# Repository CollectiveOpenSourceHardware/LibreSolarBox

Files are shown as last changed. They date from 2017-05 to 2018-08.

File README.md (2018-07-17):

# Libre Solar Box
This Open Hardware project is about the development of a solar box.
We want to provide a compact, mobile and modular electric power generator. An alternative to the diesel generator.
The power specifications are chosen to supply a mini house, a boat, a caravan, or any other off-grid devices like a music station on an open-air.

The aim is that everybody is possible to rebuild the solar box at home or at his/her favourite fablab.

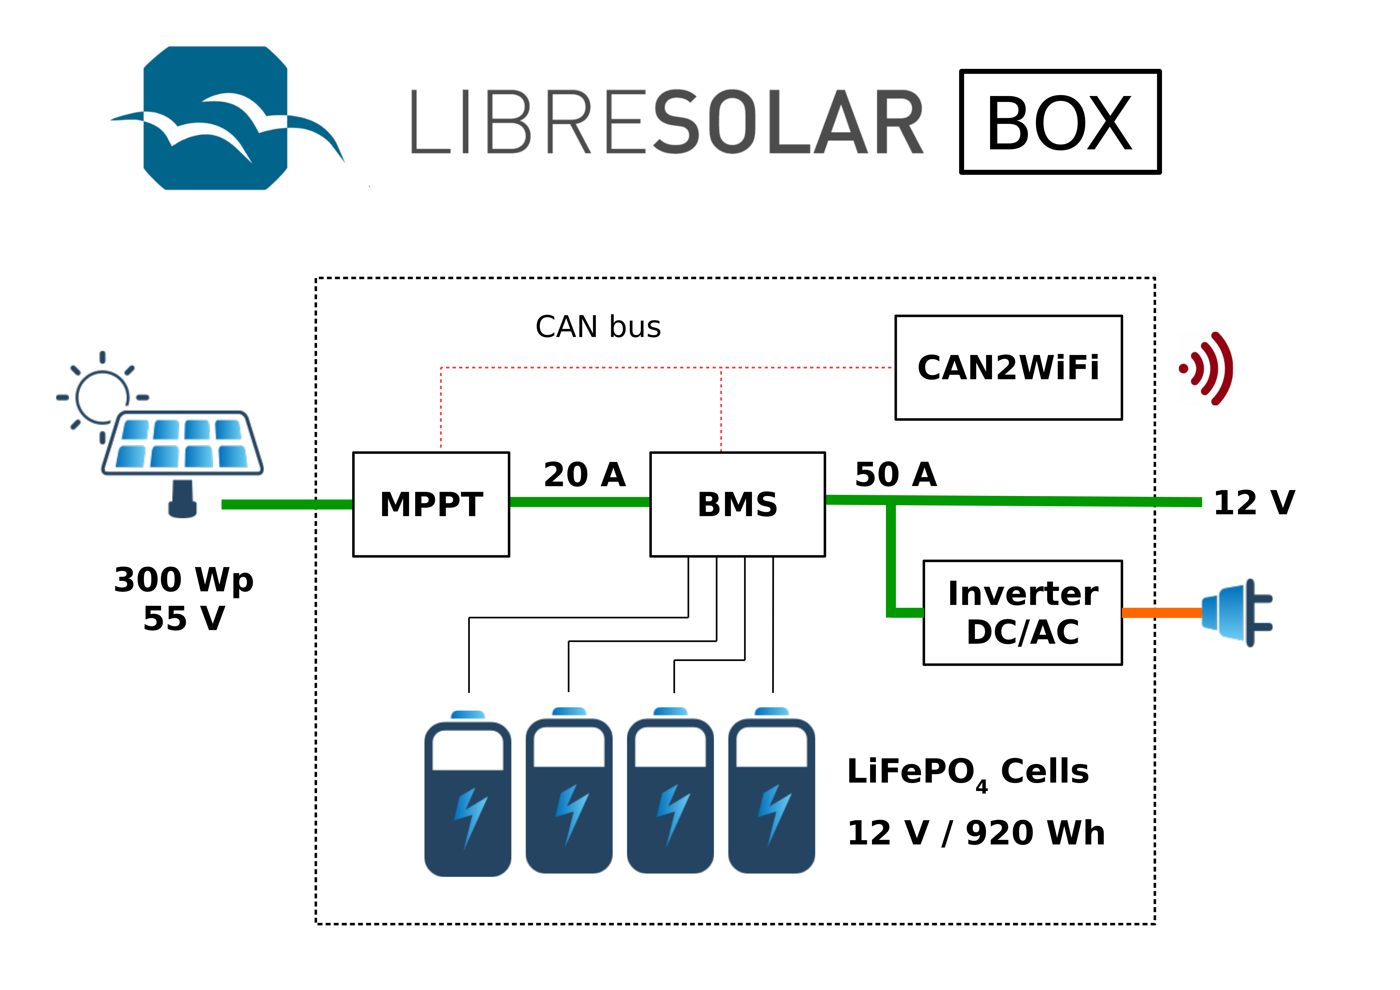
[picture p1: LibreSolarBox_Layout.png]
Layout


----------------------
## current system layout, V0.1
The current Libre Solar Box system contains following specs and modules:
### specs:
- V_input_max = 55V
- P_input_max = 300Wp
- C_batteries = 920 Wh
- V_dc_out = 12V
- P_dc_out = 300W, theoretically 600W -> not tested
- (V_ac_out = 230V, 50Hz) optional
- (P_ac_out = 250W) optional -> depend on inverter

### modules:
- **electric**: [Libre Solar](http://libre.solar/) (MPPT+BMS), Inverter (Victron), ESP/Rasbperry, Fuse
- **Batteries**: LiFePO4 (Calb), 72Ah, 3,2V, 230,5Wh - 4x -> 12,8V, 920Wh
- **Housing/Frame**: [UniProKit](https://wiki.opensourceecology.de/Upklib), with corner elements for blending; wood plates for mounting electric parts and batteries
- **Interface**: Solarinput (MC4), DC-output (car plug), AC-output (schuko, integrated in inverter), main switch

### visualization:
- [Open Energy Monitor](https://openenergymonitor.org/) via CAN to ESP (Server ext.)/Rasbperry (Server int.)
- browser based visualization -> access via LAN/WLAN

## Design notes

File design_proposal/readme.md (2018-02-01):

in this folder we want to propose some designs how you can enclosure the box components to a moveable scalable box

## First designs
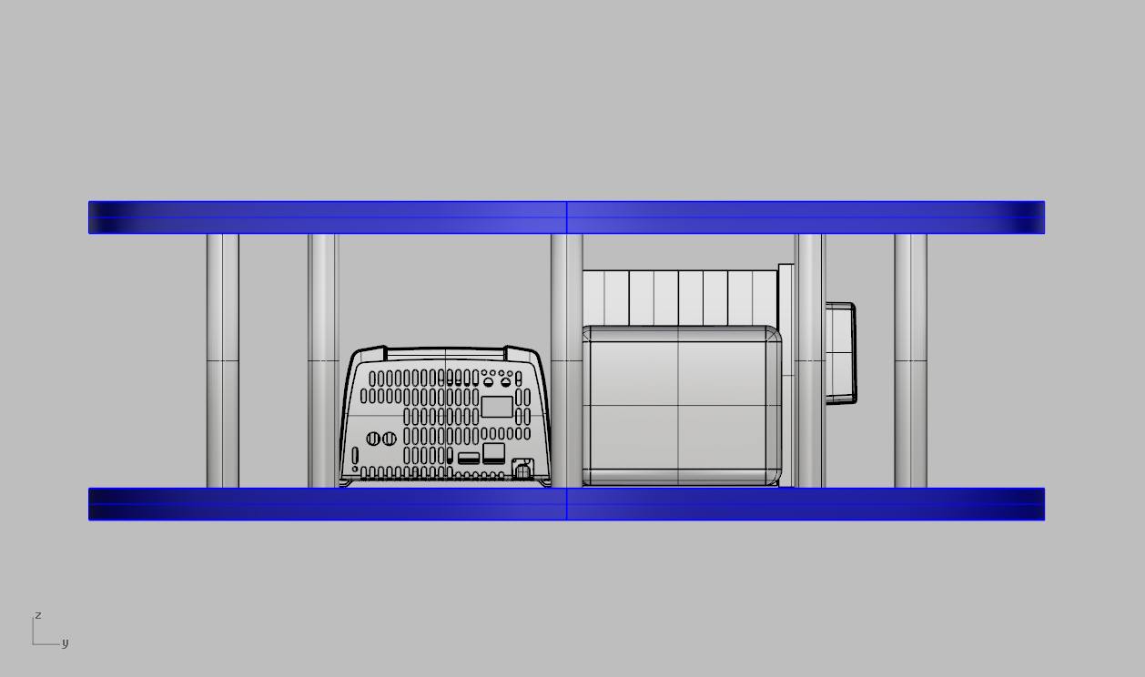
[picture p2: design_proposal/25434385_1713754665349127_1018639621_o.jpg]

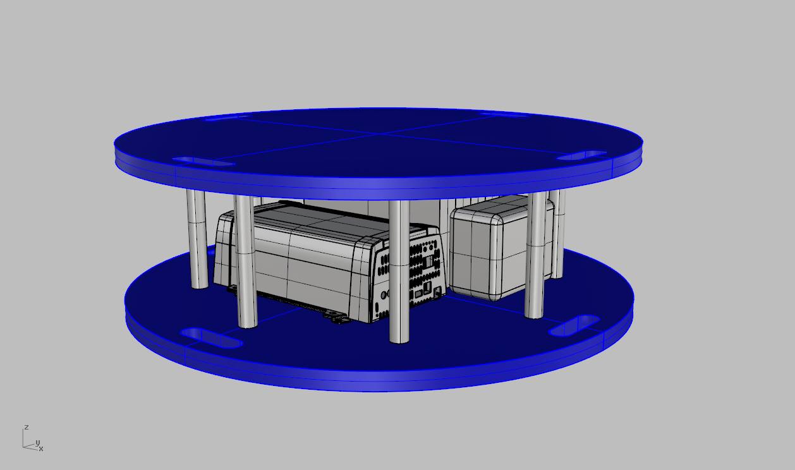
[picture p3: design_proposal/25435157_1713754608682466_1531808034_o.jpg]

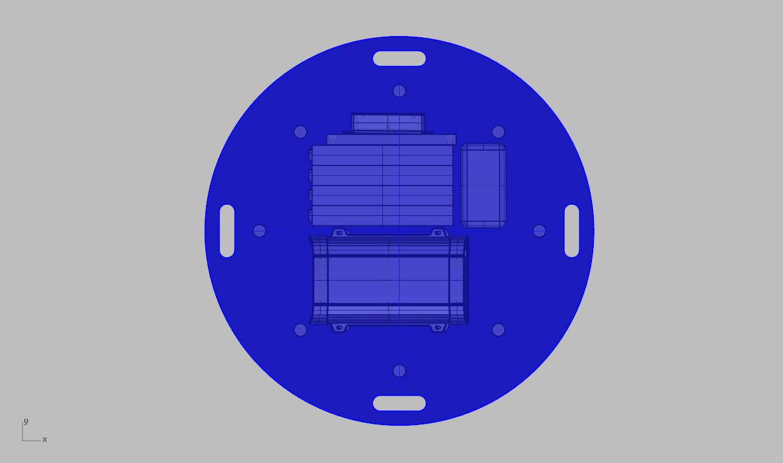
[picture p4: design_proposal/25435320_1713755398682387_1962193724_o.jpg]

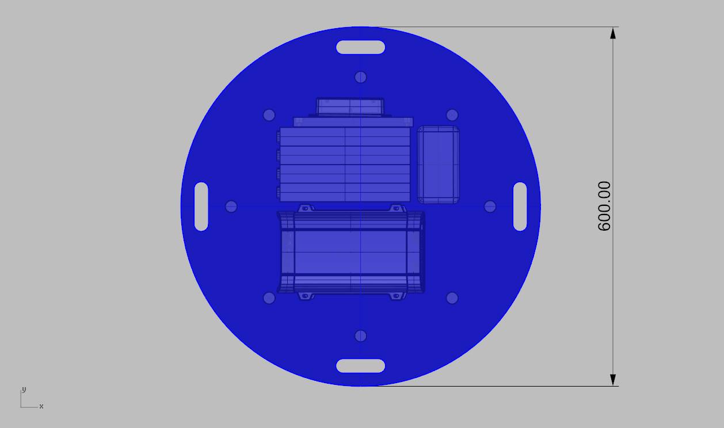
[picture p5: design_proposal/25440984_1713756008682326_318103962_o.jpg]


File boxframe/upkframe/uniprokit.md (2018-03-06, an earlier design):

## The UniProKit 

The UniProKit (Universal Prototyping Kit) project was originated by the wish to have a kind of open universal construction kit available, based on the principles of OpenSource/OpenHardware.

It should resemble the well known '''metal construction sets''' like Meccano/Erector, with basic elements like bars, angles and plates with rows of drilled holes, wheels, flanges, transmission-rods etc., up to more specific elements like stepper motors and linear drives, less toy-like, but more stable and slightly bigger dimensioned.



### Applications

Such a thing would be desirable for all kind of projects, for fast and easy testing of approaches and ideas - just rapid prototyping, or for building smaller machines like a 3D-printer or pcb-router. It could also be used for structural supports and mountings in experiments, or jigs for producing other parts. One can also use it for building assembly groups and modular components in other projects, e.g. a lineardrive-module within a tracking-system.



The application range is wide and similar like those commercial and aluminium-extrusion-profiles based T-slot-systems often used by engineers, but we dont want to be limited only on such quite expensive system-solutions. It is an important aspect of the UniPro-Kit Sets, that they are consisting mainly of these parts, which are easy and everywhere available, like in the next local hardware store. Or one can make use of materials like aluminum-profiles, which can become DIY-processed with hand-tools and simple jigs, e.g. drilling rows of holes and cutting at different lengths.

It is an important and typical part of the OSE-concept, to become independent of industrial producers, not absolutely and by 100%, but as much as possible.

### Compatibility and Systematics

Within the ongoing development of this project eventually occurred - as a kind of by-product - the idea, to make the UniPro-Kit open and extendable towards all directions and to support any possible kind of compatibility with other Open Hardware Construction sets like Gridbeam, OpenStructures and Openbuilds, etc., and to integrate and combine all these and others together into a kind of open standard.

Now we try to define conditions and criteria of a classification-systematics, in which all kind of parts from different other construction sets can become integrated and registered, getting a unique part-no., and act as a common base for a kind of catalog-system or parts-database.

Systematics

The aim and our hope is, that such parts would be preferred and more often used in many maker-projects, so that it may later results in a kind of independent de-facto-standard of OpenHardware-parts.

### Advantages 

This would offer the following advantages:

* each part that was integrated into this system contains in its database-entry at least a reference on a source of supply and a technical drawing. In some cases there may be also a detailed description how to produce this part on your own with appropriate tools and jigs ("DIY-able").

* in case of some parts which are not so easy to produce some groups or Open Hardware projects may specialize themselves on producing and offering them the Open Hardware Community to buy. This could lead into a small market with independent suppliers ( like "OpenSourceEconomy").

* the parts and their producing-process itself can be optimized by the community and better adopted at the specific demands of the individual Openhardware projects.

* one can use OpenSource-CAD-libraries of the parts, which allow a pure virtual construction, development and optimization of Open Hardware projects by a big developer-community, longtime before its necessary, to spend real money for materials or having access to well equipped workshops.

* the systematics and the database would allow a direct search and access of special parts. That's different compared to sites like thingiverse, on which also exists a lot of useful things, but they are only small organized and less catalog-like, so it needs a time-consuming search to find there the appropriate thing.

### Status 

The recent state of the project is, that we have already fully defined the so called **Basic-Set**, which is appropriate for all kind of structural framing and mounting stuff and provide it for download as part-library **UPKlib V.2**). It is made consequently with the OpenSource CAD-programm **FreeCAD**, which means it can be exported from there into many important CAD-fileformats like .igs, .stp, .stl etc.  



Other sets are under development, like the **LinearDrive Set** for linear motion of cnc-maschine-axis and the **Frame Set**, which contains useful parts for housing, like corner-elements and cover-plates.  

More sets are in preparation, each one related to a certain area or theme, like electronic-pcbs and stepper-motors. Since this is an open system, all kind of useful sets can be added by time or on demand.  Meanwhile we can use them as working-examples, for discussing and developing different contents and practical aspects of the systematics.

It would be nice and certainly useful for everyone, if such a kind of systematics could be well established as an independent standard of parts and parts lists in Open Hardware projects.  Whether this will really happen or not depends on different facts and influences, like e.g. the acceptance of the community.

### Links 
* Project-Homepage: [UniProKit](https://wiki.opensourceecology.de/Universal_Prototyping_Kit)
* The CAD-Library: [UPKlib V.2](https://wiki.opensourceecology.de/Upklib)
* Structural Parts: [Basic Set](https://wiki.opensourceecology.de/Basis-Set_Strukturelemente)
* Housing: [Frame Set](https://wiki.opensourceecology.de/Erg%C3%A4nzungs-Set_Frameset)
* Linear Motion : [LinearDrive Set](https://wiki.opensourceecology.de/Erg%C3%A4nzungs-Set_Lineartrieb)

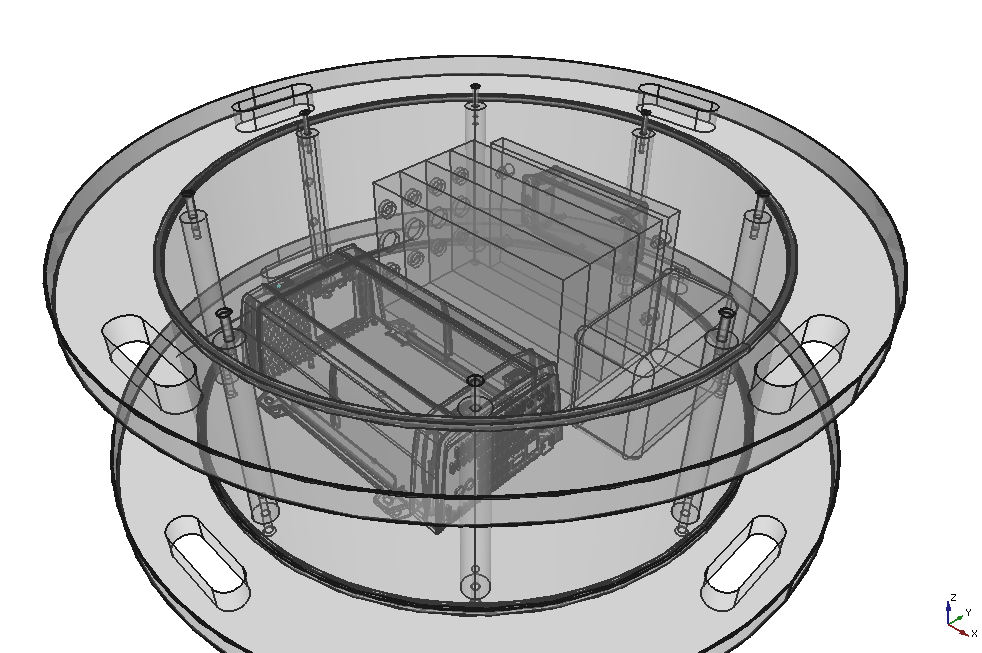
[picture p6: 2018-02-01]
design_proposal/Solarbox_Trommel_transparent.png

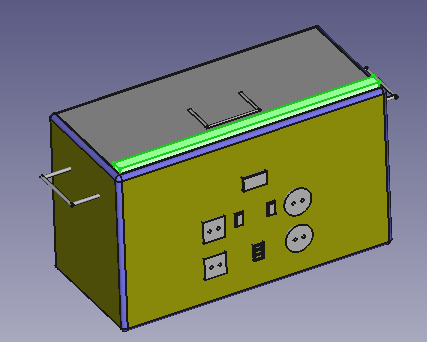
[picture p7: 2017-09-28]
Solar Box_FreeCAD Design/Solar Box v_3/solar_box_v_03_photo1.PNG

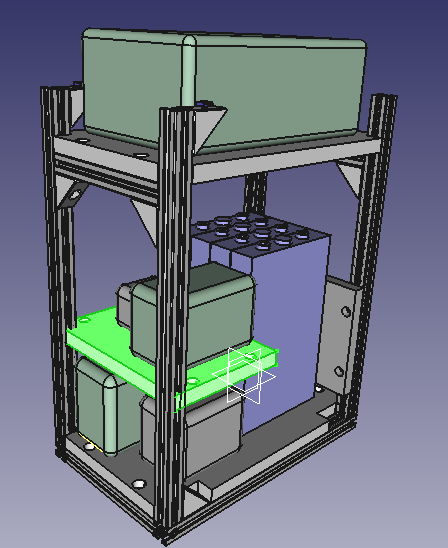
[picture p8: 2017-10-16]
Solar Box_FreeCAD Design/Solar Box v_4_ boxframe/Solarbox_v_04_boxframe_photo_2.PNG

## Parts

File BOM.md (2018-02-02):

## Bill of materials V0.2:

### Box Frame:
- UPK frame:
  - aluminium slot: size defined in 3D model
  - triangle connectors (for stabilization, @case06 whats the right word for it? :))
  - screws, ..., @case06  can you extend the list w/ all needed parts for the Uni Pro Kit w/o corner elements
- wood plates for cover -> thickness like alu profile
- wood plates for internal mounting of parts -> bottom, PCB mounting, analog V0.1
- corner elements -> 3D modelled options (@jocogergely if you can you can make few suggestions, no prio)

### Electronics:
- MPPT, BMS, Gateyway/Server
- buck converter

### Interface:
- DC output plugs (12V car plug, 2x)
- Solar input plugs: Weidmüller PV Stick (assembly w/o crimping and compatible to MC4, clips should be removed to unplug without tools)
- USB plugs
- ON/OFF switch, pushbutton, integrated LED
- RJ45 jacks (2x)
- e-paper display+conncetion wire

### Internal Connections:
- Power wire (6mm^2, red+blue, each 1m)
- Balancing wire (2mm^2, 2m)
- Communication wire (ethernet cable, 0,5m)
- Ferrules, Cable lugs

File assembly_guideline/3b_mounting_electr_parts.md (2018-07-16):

# Assembly Workshop at the Fablab St.Pauli, 08. July 2018

### Preparation Steps
- Software tools
  - FreeCAD, 
- Prepare tools and place
-> foto of each part
  - table
  - crimping tool
  - screwdriver
  - side cutter
  - allen wrench
- Prepare material and components
  - Frame and Housing (in this case UniProKit)
    - screws, nuts
    - T-slot alu profile
    - 3D printed corner elements / connectors
    - bottom plate
    - housing plates
  - Battery pack
    - 3D printed battery case (bottom and cap -> download link to file)
    - battery cells
    - cell connectors
  - electrical components
    - Libre Solar components -> MPPT, *BMS*, (optional: CAN2Wifi)
    - (optional: RaspberryPi0)
    - wires - power wires (6 sq mm), balancing wires (2 sq mm)
    - ferrules, cable lugs
    - (optional: communication wire - ethernet cable)
   - plugs
     - *dc-output plugs (car plug, 2x)*
     - solar input plugs (Weidmüller PV Stick allows assembly w/o crimping and is compatible to MC4. Clips should be removed that the plug can be unmounted without tools)
     - *usb plugs*
     - *ON/OFF switch, pushbutton, integrated LED*
     - (optional: RJ45 jacks (2x))
     - (optional: epaper display+conncetion wire)

Remarks: Parts in *italic font* still need to be ordered.

### Assembly Steps
1. Frame assembly
- 1.1 nuts into t-slot profile (

//comment from Oliver: fotos, which shows for each side the placement (and numbers) of the nuts (sitting in the slots). This is the key-information needed when assembling a box the first time, in order to avoid repeatedly re-opening the frame for adding some forgotten nuts

- 1.2 place profile in rectangle, place corner elements between profiles, screw together
- 1.3 repeat 
- -> result: 2 connected rectangle frame
- 1.4 connect the 2 rectangle frames with profile
- -> result: boxframe
2. screw bottom plate on bottom side of boxframe
- -> result: boxframe with bottom plate
3. cut and crimping wires
- 3.1 ...
4. battery pack assembly -> !!!!!safety note!!!!!
- 4.1 put battery cells in battery case (bottom part)
- 4.2 connect battery cells together
- 4.3 connect balancing wires with cells
- 4.4 connect power wires with battery cells
- 4.5 screw battery pack with bottom plate
5. mouting of electric components
...

### Disassembly Steps
1. remove blending parts (sides, backs)
-> pic box, mark sides, mark screws
2. remove fuse! -> no voltage/ current in system, note for electric safety rules 
-> pic fuse
3. remove interface (plugs, swith), by cutting, by 
-> pic interface, mark points to remove
4. remove cables from electric components
-> pic components, pic interface/jack
5. demount electric parts
-> pic screws
6. 

## Disassembly ##
### Disconnect BMS:
* Remove fuse.
* Remove BAT+ cable. 
* Mask metal end of the cable .
* Remove BAT- cable.
* Mask metal end of the cable.
* Remove PWR+ cables from BMS.
* Remove PWR- cables from BMS.
* Remove thin cables from BMS
* Remove internet cables from BMS.
* Remove monitor cables.
* Move ends of the cable down. Keep them away from batteries.
* Remove thin cables.

### Remove upper part of the case
* Remove screws from the upper blending.
* Remove screws from handles.
* Remove the upper blending with the handles.

### Remove interface blending
Interface are the sockets on the blending.

* Remove thick cables from blending if they are not soldered.
* Remove screws from the blending. Put them into a cup.
* Desolder on/off-swich.
* Remove CAN Socket.
* Remove USB power socket.
* Remove two DC Out 1V sockets.
* Do not remove PV INPUT and OUTPUT from interface. In this version it is not mechanically possible yet. We need to disconnect them from MPPT first.
* Remove PV Input and OUTPUT cables from MPPT.
* Remove all other cables from MPPT.
* Remove the interface bleding.
* Remove PV Input and OUTPUT sockets with cables. Now it is possible to do.
* Put away the interface blending.

### Remove MPPT
* Remove screws which hold the MPPT.
* Put away MPPT.

### Remove BMS
* Remove screws which hold BMS at the battery case.
* Put away BMS.

### Remove remaining side blendings
* Remove remaining side blending and put them away.

Now you can easier access the batteries.

### Remove batteries
* Determine the in wich order you need to remove the batteries. We work from **main -** -- this is the first battery -- to **main +** -- this is the last battery.
* Carefully remove a screw, an electric connector, and a washer from one side of a battery block.
* Carefully remove a screw, an electric connector, and a washer from the other side of the battery.
* Put away the battery.
* Repeat it for all the remaining batteries.

### Dissassemble frame
* Lay the frame on a side. This is the side with the largest area.
* Remove four upper screws.
Before remove the frame, pay attention to the nuts in the frame. They can fall down after the next step.
* Put away the frame.
* Remove four screws which connects the remaining frame with the small aluminum profiles.

We have now two frames and for short aluminiums profiles.

* Remove screws throw the plastic corners of the both frames.
* Remove the plastic corners.

## Assembly
### Assembly frame box
Note: square nuts are not symmetric. When inserting them into T-Slot, keep the upper part outside. See picture [...] to determine the upper side of the nuts.

Create large squre frames first.

* Put larger profiles on the table and put plastic corners in the corners. Check orientation of the profiles. The holes on the side of the upper and the lower profile must be up.
* Insert all necessary square nuts in the T-slots.

 Hint: Use a bolt to push a square nut into a slot.

* Control the placement of corners, screws and squre nuts.
Start with the bottom part.
* Connect a corner to the bottom.
* Connect a side part to the bottom.
* Connect another corner to the bottom.
* Connect another side to the bottom.
* Connect remaining corners and the upper part.
* Connect small T-profiles to a big square frame. The holes on the side of the large frame must be later outside of the box.
* Insert nuts into short profiles. Two nuts into every short profiles on the top of the future box. Four nuts into every short profile on the bottom of the future box.

### Add bottom
* Add the bottom blending.

### Add batteries
* Mark the batteries with numbers *1*, *2*, *3*, and *4*.
* Put batteries into the battery case.
* Isolate main **+** and main **-** of the batteries. (Is it important to have main "+" or "-" on particular side of the battery block?")
Now carrefully connect batteries one by one, from *4* to *1*.
* Put connector between *4* and *3*.
* Put a washer on the connector on the side *4*.
* Put thin cable with tag *4* on the washer
* Put another washer on the connector of the thin cable. (Too many washers, check it again).
* Put a bolt throw connector, washers and thin cable and  tighten it. (bots or screws?).
* Put a washer on connector on side *3*.
* Put a bolt throw the washer and the connector and tighten it.
* Connect in the simmilar way batteries *3* with *2* and *2* with *1*.
* Do **not** remove isolation from main **+** and main **-** yet.

### Assembly interface bleding
The interface blending is the blending with sockets.
* Put sockets with cables into the blending
* Mount the interface bleding to the frame

### Connect BMS
* Solder cablers to the on/off-switch.
* Mount blue thick cables and USB+ to *PWR-* of BMS.
* Mount red thick cables and USB- to *PWR+* of BMS.
* Connect two blue cables (- or +?) to two DC out sockets.
* Connect two red cables to two DC out sockets.
* Connect two thin cables from on/off-switch to BMS.

### Connect to MPPT
* Connect all cable ends without blade connectors to MPPT.
* Check that these cable are well mounted.

### Connect battery block
(In this part BAT- and BAT+ seems to be confused.I need resolve it.)
* Remove isolation from **main -**.
* Connect two cables to **main -**.
* Connect thick blue cable to *BAT-* on BMS.
* Connect two cables to **main -**
* Connect balancing to *BAT-* on BMS. (Is this correct?)
(Must the on/off switch must be off before add the fuse? How one can see it?)
* Add fuse.
* Check the voltage (where?): It must be around 12.8 V.
* Switch off the on/off switch.
* Check the voltages. It must be falling until 0. The voltage does not drop imidiatelly to 0, because there is remaining electric charge in the capacitors.
* Swich on.
* Check Voltage between *POW+* and *POW-*. It must be about 12.8V.
* Remove the fuse. (I missted this step in my notes. Is it correct here?).

### Connect Raspberry
* Connect  an internet cable to Raspberry
* Connect the internet cable to BMS.
* Connect an internet cable to CAN socket on the blending.
* Connect the other end of the cable to BMS.
* Mount the Raspbery with two-side tape to the box.

### Add back blending
(Better do it before interface blending because the inteface blending is not flat.)
* Put SolarBox on the interface.
* Position square nuts. They must have the same position as the holes of the blending.
* Put blending on the frame.
* Insert bolts through the blending into the square nuts. Tighten the bolts.

### Mount side blending
* Put the SolarBox on the side.
* Position the squre nuts.
* Put the blending on the frame.
* Insert bolts through the blending into the square  nuts. Tighten the bolts.

### Mount to blending with handles.
* Put the SolarBox on the bottom.
* Position squre nuts for the top blending.
* Put top blending.
* Put handles on the top blending.
* Insert **longer** bolts through the handles, the blending and squre nuts. Use normal bolts for other parts of the blending.
* Tighten the blending.

### Mount last side blending
* Check once more if all the connection are good.
* Insert the fuse.
* Put the SolarBox on the side.
* Position the square nuts.
* Add the blending.
* Tighten the bolts.

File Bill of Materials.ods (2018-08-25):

# | Material | quantity | Material/design type/ comments | dimention | Manufacturer | Supplier/Seller | Price
1 | Uni Pro kit (UPK) | 1 set |  |  |  | Oliver
2 | Wooden side plates | 4 plates | wooden ply |  |  | Oliver
3 | Acrelic side plate cover | 1 plate | tranperant |  |  | Oliver
4 | Wooden bottom plates | 1 plate | wooden ply |  |  | Oliver
5 | Wooden Extra plates for battery Holder |  | wooden ply |  |  | Oliver
6 | Battery Holder 3D printed | 1
7 | Handel 3D printed | 2 | 3d printed |  |  | Oliver
8 | Corner 3D printed | 4 | to assumble UPK part
9 | Fuse | 1
10 | Display | 1
11 | MPPT | 1
12 | BMS | 1
13 | Inlet + Outlet Solarpanel connector | 1 set
14 | DC 12V outlet plug | 2
15 | USB 5V outlet plug | 1
16 | CAN output plug | 1
17 | On/Off button | 1
18 | Battery Cell | 4
19 | Battery Cell connector plates | 3
20 | Battery Cell connector screw | 8
21 | RasPi - CAN to wifi connection | 1
22
23
24
25 | Screw - Handel of UPK | 4
26 | Small Screw - outer panel of UPK
27 | Nut for outer panel of UPK
28 | Big cornor Screw - to addemble UPK frame in cornor | 8
29
30 | Screw - MPPT/BMS connection | 10 | 5x2
31 | Screw - MPPT/BMS installation | 8 | 4x2
32 | Disply | 1
33
34
35
36
37 | Wire - thick - red & blue | 10 | to all main connection from battery to MPPT & BMS | 0.25m (5 Red color & 5 Blue colour)
38 | Wire - thin - blue | 6 | to connect BMS to battery to check Battery status | 0.4mx6 (blue colour)
39 | Wire - very thin - black | 3 | to connect power button to MPPT | 0.25mx2, 0.4mx1
40 | LAN cables | 3 |  | 0.25 m
41 | wire connectors

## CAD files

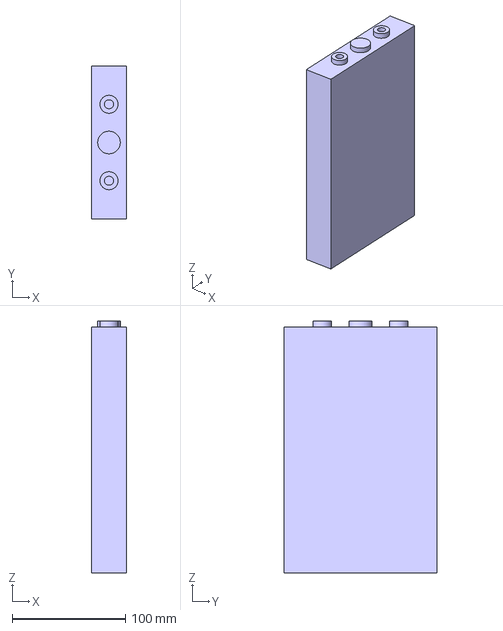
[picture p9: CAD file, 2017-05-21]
batterycase/celltypes/CALB_CAM72/cam72_calb3.fcstd
31.0 x 135.1 x 222.5 mm

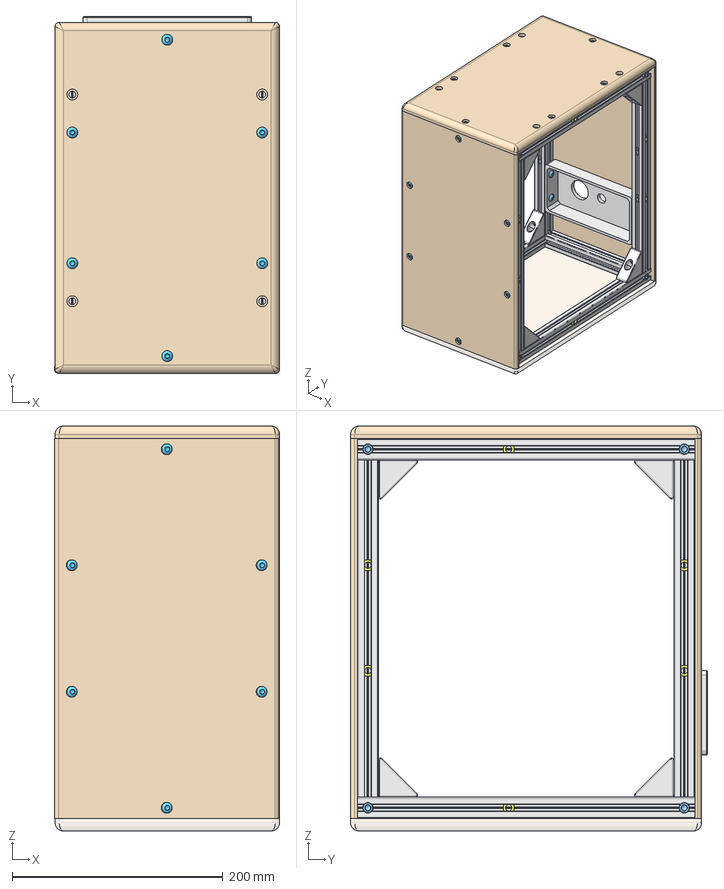
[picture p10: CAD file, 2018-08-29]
boxframe/buildinstructional/cover/cover8.fcstd
213.5 x 338.5 x 384.0 mm
tslot32con
tslot16
tslot16_001
tslot32con_001
M6x25-Screw
M6x25-Screw004
M6x25-Screw005
M6x25-Screw006
tslot32con001
tslot041
tslot16_002
tslot32con_002
M6x25-Screw012
M6x25-Screw015
M6x25-Screw017
M6x25-Screw016
m6nutplate020uf
m6nutplate021lf
m6nutplate022lf
m6nutplate023lf
m6nutplate024lf
m6nutplate025lf
m6nutplate026lf
m6nutplate027lf
m6nutplate028uf
m6nutplate029uf
m6nutplate030lf
m6nutplate031lf
m6nutplate032uf
m6nutplate033lf
upright4
m6nutplate025uf001
m6nutplate022uf001
m6nutplate031lf001
M6x12-Screw022
upright005
m6nutplate031lf002
M6x12-Screw025
upright006
m6nutplate031lf003
M6x12-Screw028
upright007
m6nutplate031lf004
M6x12-Screw031
m6nutplatesidecover
m6nutplatesidecover001
m6nutplatesidecover002
m6nutplatesidecover003
m6nutplatesidecover004
m6nutplatesidecover005
m6nutplatesidecover006
m6nutplatesidecover007
m6nutplatefrontcover
m6nutplatefrontcover001
m6nutplatefrontcover002
m6nutplatefrontcover003
m6nutplatefrontcover004
m6nutplatefrontcover005
m6nutplatefrontcover006
m6nutplatefrontcover007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

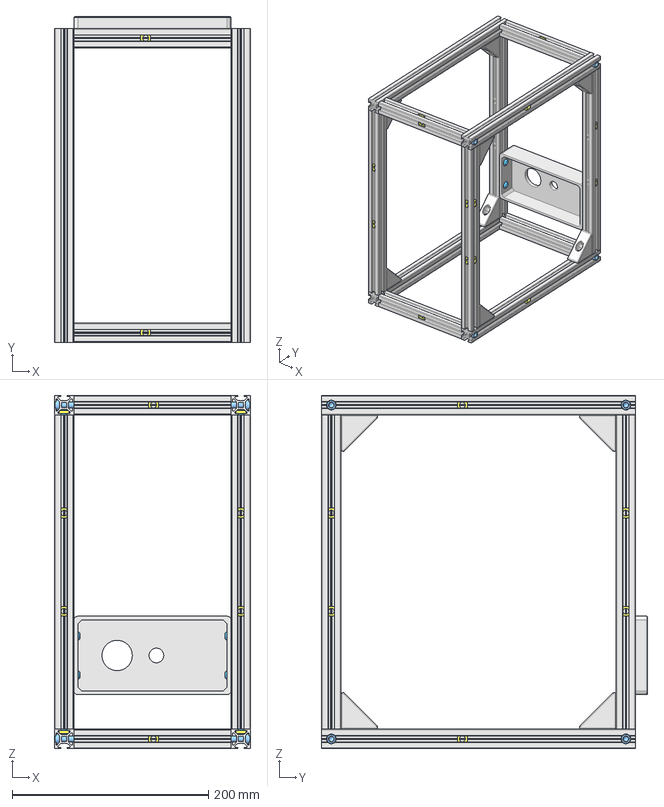
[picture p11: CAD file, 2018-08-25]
boxframe/buildinstructional/ifmountframe/ifmountframe1.fcstd
200.0 x 332.0 x 360.0 mm
tslot32con
tslot16
tslot16_001
tslot32con_001
M6x25-Screw
M6x25-Screw004
M6x25-Screw005
M6x25-Screw006
tslot32con001
tslot041
tslot16_002
tslot32con_002
M6x25-Screw012
M6x25-Screw015
M6x25-Screw017
M6x25-Screw016
m6nutplate020uf
m6nutplate021lf
m6nutplate022lf
m6nutplate023lf
m6nutplate024lf
m6nutplate025lf
m6nutplate026lf
m6nutplate027lf
m6nutplate028uf
m6nutplate029uf
m6nutplate030lf
m6nutplate031lf
m6nutplate032uf
m6nutplate033lf
upright4
m6nutplate025uf001
m6nutplate022uf001
m6nutplate031lf001
M6x12-Screw022
upright005
m6nutplate031lf002
M6x12-Screw025
upright006
m6nutplate031lf003
M6x12-Screw028
upright007
m6nutplate031lf004
M6x12-Screw031
m6nutplatesidecover
m6nutplatesidecover001
m6nutplatesidecover002
m6nutplatesidecover003
m6nutplatesidecover004
m6nutplatesidecover005
m6nutplatesidecover006
m6nutplatesidecover007
m6nutplatefrontcover
m6nutplatefrontcover001
m6nutplatefrontcover002
m6nutplatefrontcover003
m6nutplatefrontcover004
m6nutplatefrontcover005
m6nutplatefrontcover006
m6nutplatefrontcover007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

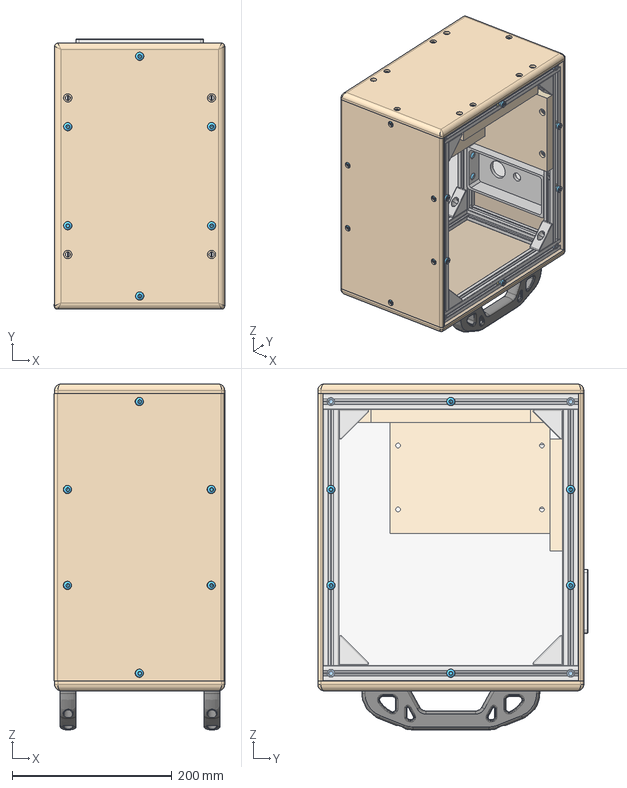
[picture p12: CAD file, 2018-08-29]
boxframe/buildinstructional/innerplates/innerplate6.fcstd
213.5 x 338.5 x 433.0 mm
tslot32con
tslot16
tslot16_001
tslot32con_001
M6x25-Screw
M6x25-Screw004
M6x25-Screw005
M6x25-Screw006
tslot32con001
tslot041
tslot16_002
tslot32con_002
M6x25-Screw012
M6x25-Screw015
M6x25-Screw017
M6x25-Screw016
m6nutplate020uf
m6nutplate021lf
m6nutplate022lf
m6nutplate023lf
m6nutplate024lf
m6nutplate025lf
m6nutplate026lf
m6nutplate027lf
m6nutplate028uf
m6nutplate029uf
m6nutplate030lf
m6nutplate031lf
m6nutplate032uf
m6nutplate033lf
m6nutplate023
upright4
m6nutplate025uf001
m6nutplate022uf001
m6nutplate031lf001
M6x12-Screw022
upright005
m6nutplate031lf002
M6x12-Screw025
upright006
m6nutplate031lf003
M6x12-Screw028
upright007
m6nutplate031lf004
M6x12-Screw031
m6nutplatesidecover
m6nutplatesidecover001
m6nutplatesidecover002
m6nutplatesidecover003
m6nutplatesidecover004
m6nutplatesidecover005
m6nutplatesidecover006
m6nutplatesidecover007
m6nutplatefrontcover
m6nutplatefrontcover001
m6nutplatefrontcover002
m6nutplatefrontcover003
m6nutplatefrontcover004
m6nutplatefrontcover005
m6nutplatefrontcover006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

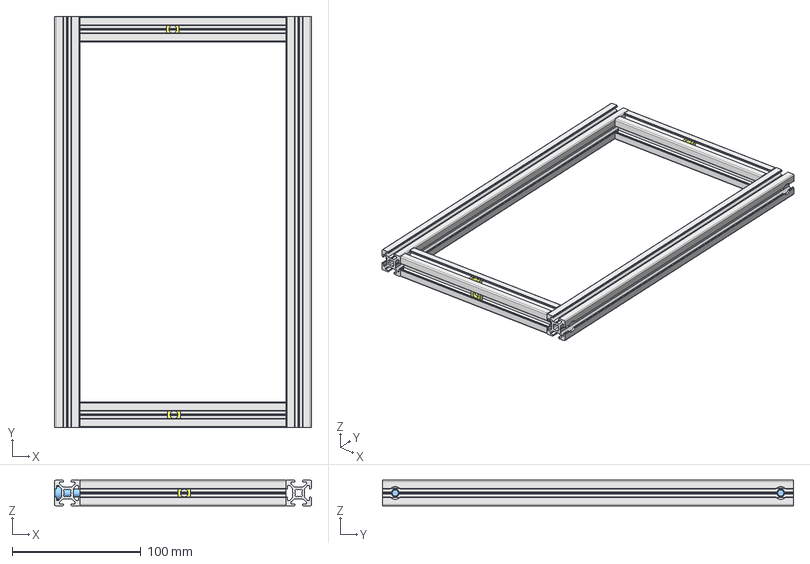
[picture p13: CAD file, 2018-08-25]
boxframe/buildinstructional/lower_frame/lowerframe1.fcstd
200.0 x 320.0 x 20.0 mm
tslot32con001
tslot041
tslot16_002
tslot32con_002
M6x25-Screw007
M6x25-Screw008
m6nutplate020
m6nutplate021
m6nutplate022
m6nutplate023
m6nutplate024
m6nutplate025
m6nutplate026
m6nutplate027

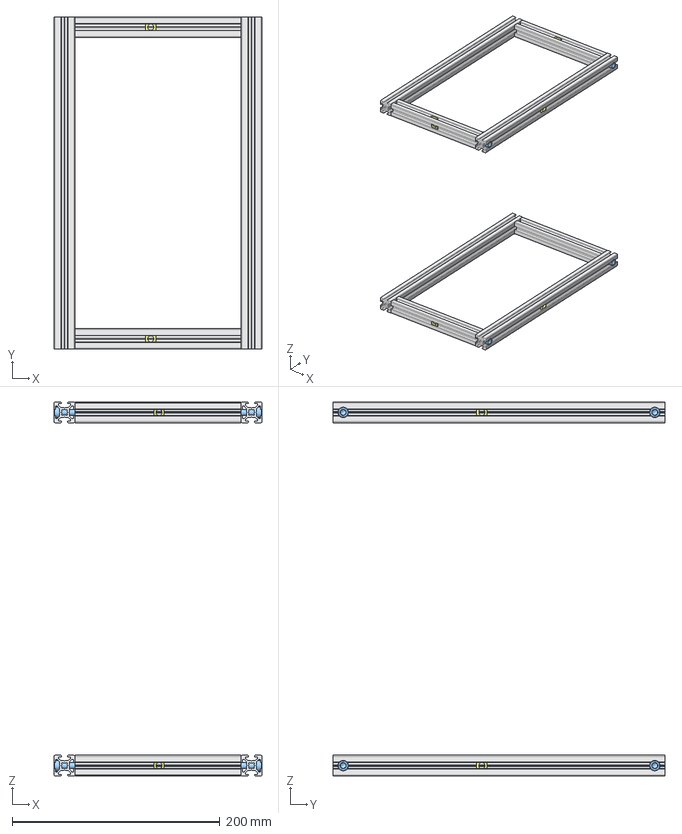
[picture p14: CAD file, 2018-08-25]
boxframe/buildinstructional/rawframe/rawframe2.fcstd
200.0 x 320.0 x 360.0 mm
tslot32con
tslot16
tslot16_001
tslot32con_001
M6x25-Screw
M6x25-Screw004
M6x25-Screw005
M6x25-Screw006
tslot32con001
tslot041
tslot16_002
tslot32con_002
M6x25-Screw012
M6x25-Screw015
M6x25-Screw017
M6x25-Screw016
m6nutplate020uf
m6nutplate021lf
m6nutplate022lf
m6nutplate023lf
m6nutplate024lf
m6nutplate025lf
m6nutplate026lf
m6nutplate027lf
m6nutplate028uf
m6nutplate029uf
m6nutplate030lf
m6nutplate031lf
m6nutplate032uf
m6nutplate033lf
m6nutplate025uf001
m6nutplate022uf001

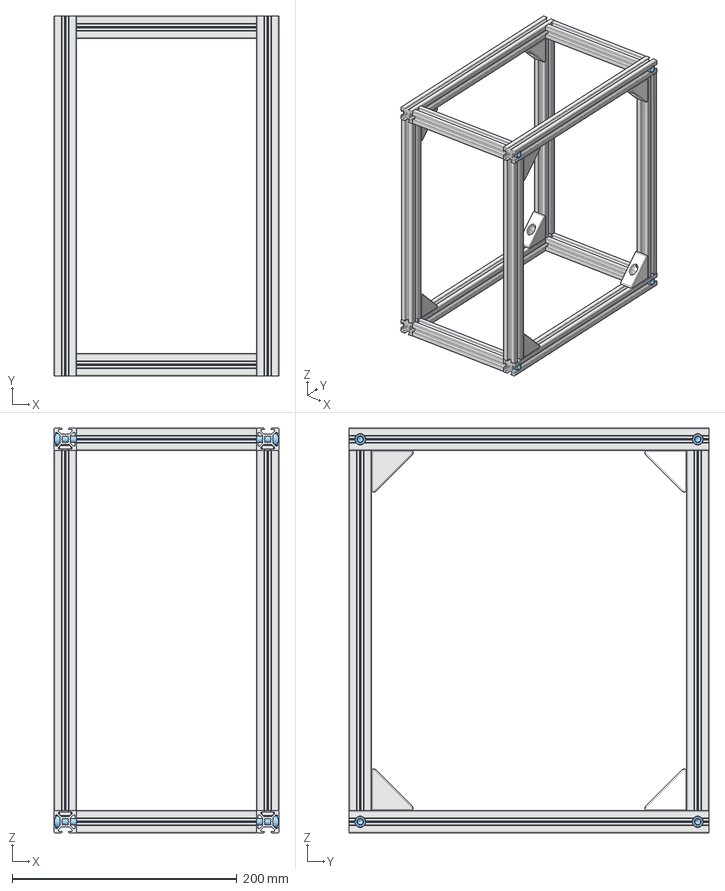
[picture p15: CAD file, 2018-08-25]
boxframe/buildinstructional/rawframeNG2b.fcstd
200.0 x 320.0 x 360.0 mm
tslot32con
tslot16
tslot16_001
tslot32con_001
M6x25-Screw
M6x25-Screw004
M6x25-Screw005
M6x25-Screw006
tslot32con001
tslot041
tslot16_002
tslot32con_002
M6x25-Screw007
M6x25-Screw008
M6x25-Screw009
M6x25-Screw010
m6nutplate002
M6x12-Screw002
M6x12-Screw003
m6nutplate003
m6nutplate
M6x12-Screw
M6x12-Screw001
m6nutplate001
m6nutplate004
M6x12-Screw004
M6x12-Screw005
m6nutplate005
m6nutplate006
M6x12-Screw006
M6x12-Screw007
m6nutplate007
tslot32
tslot32_001
tslot32_002
tslot32_003

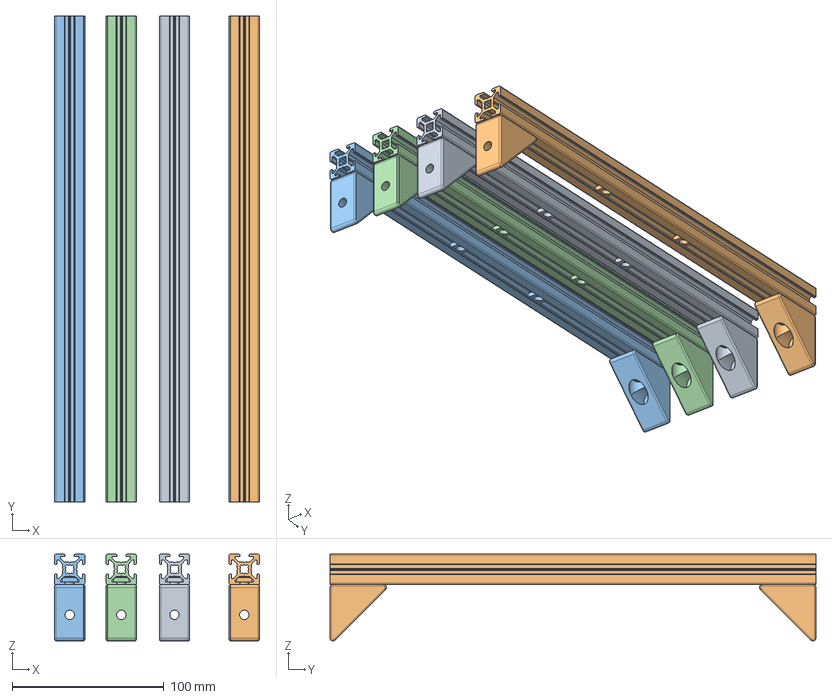
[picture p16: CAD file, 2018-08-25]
boxframe/buildinstructional/upright/upright5_all.fcstd
135.0 x 320.0 x 57.2 mm

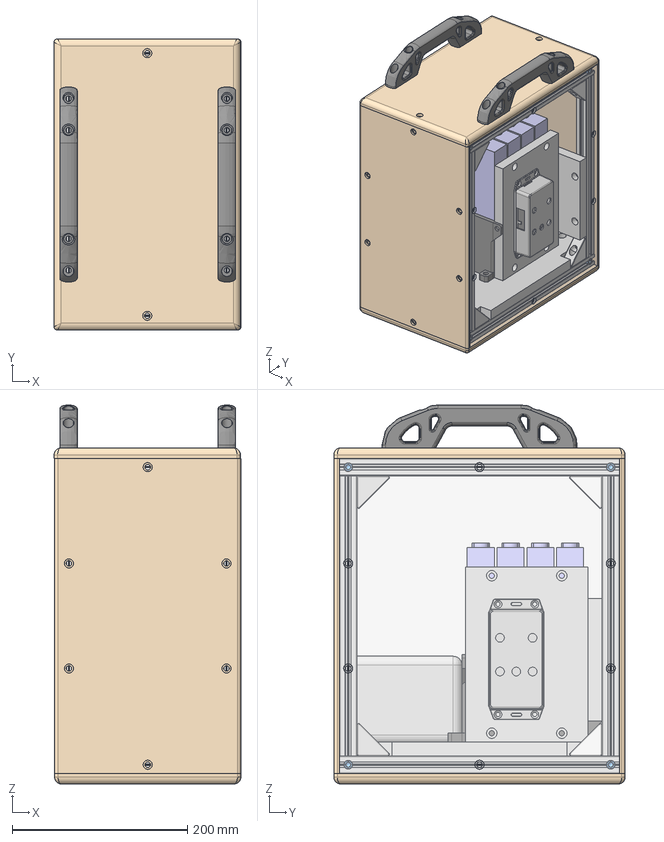
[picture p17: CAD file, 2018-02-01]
boxframe/upkframe_v6/UPKframeNG2g.fcstd
213.5 x 333.0 x 433.0 mm
tslot32con
tslot16
tslot16_001
tslot32con_001
M6x25-Screw
M6x25-Screw004
M6x25-Screw005
M6x25-Screw006
tslot32con001
tslot041
tslot16_002
tslot32con_002
M6x25-Screw007
M6x25-Screw008
M6x25-Screw009
M6x25-Screw010
m6nutplate002
M6x12-Screw002
M6x12-Screw003
m6nutplate003
m6nutplate
M6x12-Screw
M6x12-Screw001
m6nutplate001
m6nutplate004
M6x12-Screw004
M6x12-Screw005
m6nutplate005
m6nutplate006
M6x12-Screw006
M6x12-Screw007
m6nutplate007
tslot32
tslot32_001
tslot32_002
tslot32_003
front_plate
bottom_plate
MPPT
1591XXBF LID
bms-cover
bmsmounting_plate
batterymount
cam72
cam72_001
cam72_002
cam72_003
backCover
frontCover
topCover
bottomCover
sideCover
sideCover001
handle
handle001

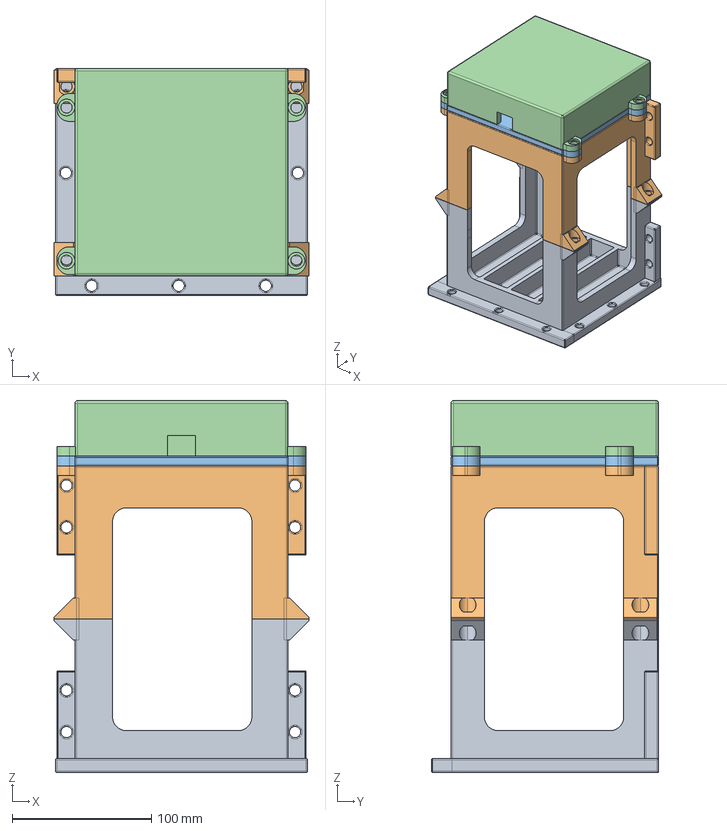
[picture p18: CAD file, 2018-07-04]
Solar Box_FreeCAD Design/Battery_Case_Holder_FreeCAD_Design/Battery Case_Holder_v_4.2_simplified.FCStd
183.0 x 163.2 x 267.0 mm
Lower_part_1
Upper_part_2
Top_sheet_3
Cover_part_4

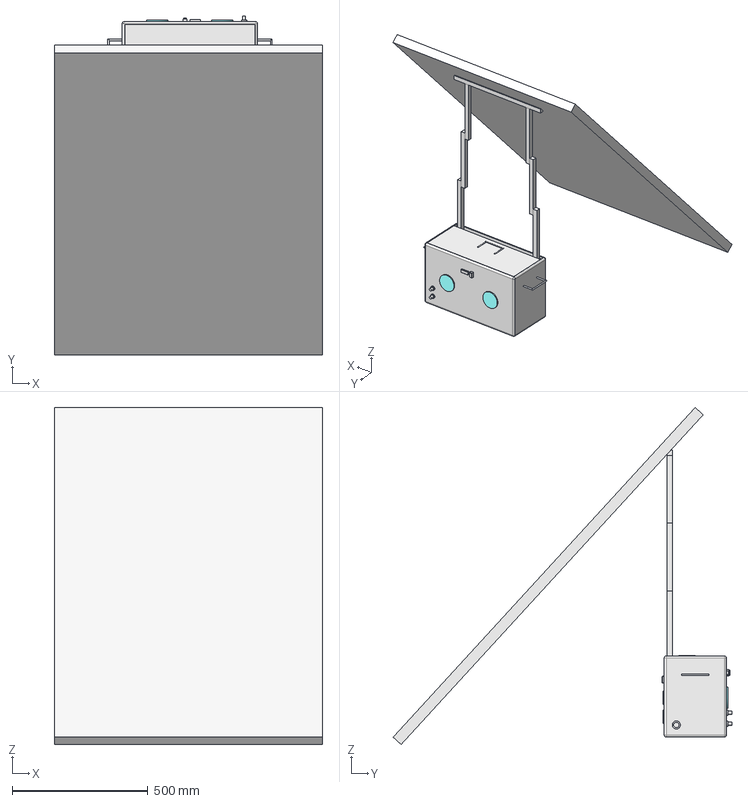
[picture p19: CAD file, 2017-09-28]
Solar Box_FreeCAD Design/Solar Box v_3/HOOU_FreeCAD_Solar_Box_v_03.FCStd
990.0 x 1250.0 x 1243.5 mm
Fan 1
AKKU 001
AKKU 002
AKKU 003
AKKU 004
Akku_pack
Fan 2
Box partation
PV Input Plug001
PV Input Plug002
Solar Box
Fan Switch
Temp. Disply
Main Disply
AC Plug 1
AC Plug 2
DC Plug 1
DC Plug 2
USB Plug
DC Plug Switch
AC Plug Switch
Invertor
MPPT
switching Box
Fuse Box
BMS
Handle Left
Handle Right
Solar Box Top cover
Solar panel supporter
Solar Panel
Micro Grid Plug

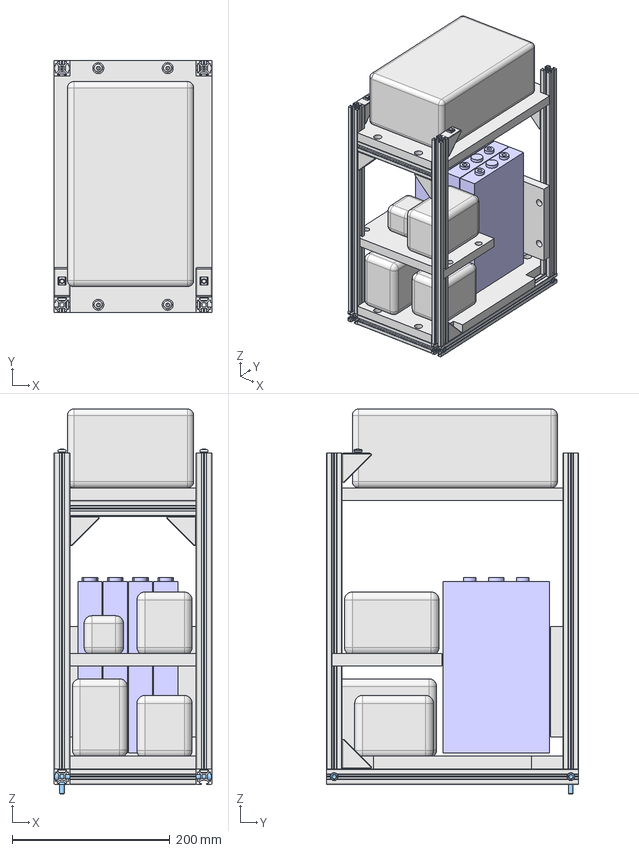
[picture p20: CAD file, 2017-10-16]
Solar Box_FreeCAD Design/Solar Box v_4_ boxframe/Solarbox_v_04_boxframe.FCStd
200.0 x 320.0 x 488.0 mm
tslot40
tslot32con
tslot16
tslot16_001
tslot32con_001
M6x25-Screw
M6x25-Screw004
M6x25-Screw005
M6x25-Screw006
tslot32con001
tslot041
tslot16_002
tslot32con_002
M6x25-Screw007
M6x25-Screw008
M6x25-Screw009
M6x25-Screw010
tslot042
tslot043
tslot044
tslot16_across
tslot16_across001
M6x12-Screw024
M6x12-Screw025
M6x12-Screw026
M6x12-Screw027
top_plate3
M6x12-Screw028
M6x12-Screw029
M6x12-Screw030
M6x12-Screw031
bottom_plate
cam72calb3
cam72calb004
cam72calb005
cam72calb006
M6x12-Screw032
M6x12-Screw033
M6x12-Screw034
M6x12-Screw035
front_plate
Invertor
MPPT
switching Box
Fuse Box
BMS

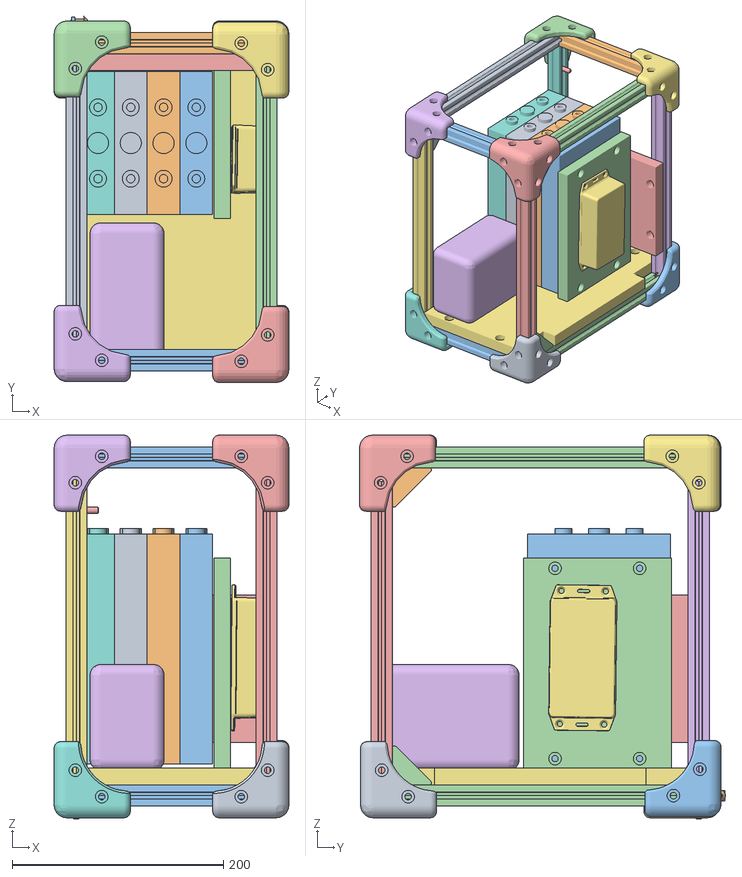
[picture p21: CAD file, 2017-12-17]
Solar Box_FreeCAD Design/Solar Box v_6_boxframe/Solarbox_v_06_boxframe - obj.obj
222.0 x 346.2 x 363.0
Screw
Screw001
Screw002
Screw004
Screw005
Screw006
Screw007
Screw008
Screw018016
Screw018013
Screw018011

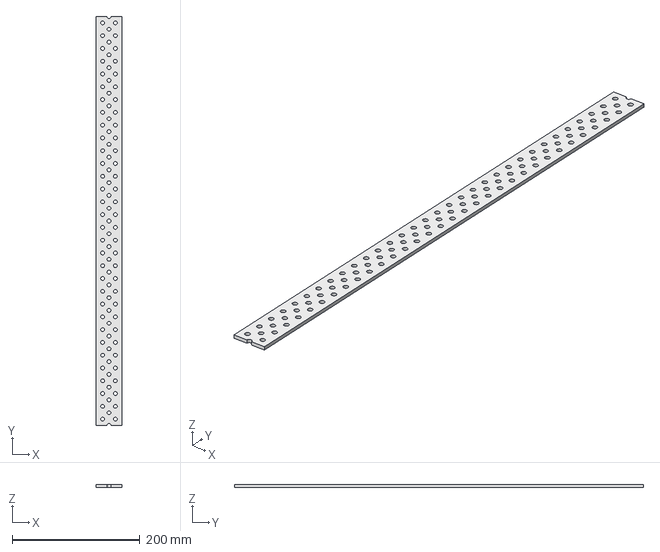
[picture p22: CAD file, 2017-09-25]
upklib_v2/flachprofile/flatplate64.fcstd
40.0 x 640.0 x 4.00 mm

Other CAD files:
boxframe/buildinstructional/upper_frame/upperframe12.fcstd
upklib_v2/frameset/3dprint-stls/shell_corner10n_xrot_x1.02.stl
upklib_v2/frameset/shell_3dcorner8g.fcstd
upklib_v2/lineardrive/gt2pulley.fcstd
Solar Box_FreeCAD Design/Solar Box v_1/HOOU_FreeCAD_Solar_Box_v_01.FCStd
Solar Box_FreeCAD Design/Solar Box v_2/HOOU_FreeCAD_Solar_Box_v_02.FCStd
boxframe/buildinstructional/cover/cover1.fcstd
boxframe/buildinstructional/cover/cover10.fcstd
boxframe/buildinstructional/cover/cover11.fcstd
boxframe/buildinstructional/cover/cover12.fcstd
boxframe/buildinstructional/cover/cover2.fcstd
boxframe/buildinstructional/cover/cover3.fcstd
boxframe/buildinstructional/cover/cover4.fcstd
boxframe/buildinstructional/cover/cover5.fcstd
boxframe/buildinstructional/cover/cover5b.fcstd
boxframe/buildinstructional/cover/cover6.fcstd
boxframe/buildinstructional/cover/cover7.fcstd
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

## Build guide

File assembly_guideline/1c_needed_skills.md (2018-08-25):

---
title: "Needed Skills"
permalink: /education/solarbox_assemblyguide/needed_skills/
---

For the successful performance of the following step-by-step instructions some prior knowledge is necessary which is not described in detail.
In addition to general computer skills this also includes basic knowledge in programming and electrical engineering.
The following points give you an overview of the prior knowledge needed.

## ns_com <br /> General Computer Skills

Dealing with a computer is almost a common knowledge in our time. For the step-by-step instructions you need computer skills for
- Working with the file explorer
- Installation of software programs downloaded from the Internet
- Knowledge of standard interfaces (like USB-port, LAN)

## ns_c <br /> Basic Knowledge in C/C++

The programming languages C and C++ are the most commonly used languages. They are especially helpful in hardware-related context which means to control physical systems by using these programming languages.
Do not worry, for the step-by-step guide you do not need profound programming skills. However you should be able to understand the basic syntax of C and C++ to be able to read and adapt some code blocks:
- Adjustment of configuration parameters <br>  (the software can be adapted to use different battery types)
- Flashing the Firmware on the embedded µC (Microcontroller)

## ns_eng <br /> Basic Knowledege in Electrical Enginnering

You should have a basic understanding of electrical behavior. What is current, what is voltage and what does electrical resistance mean? We will not explicitly answer these questions. An introduction to that topic can be found in the following Wikipedia entry [Electrical Network](https://en.wikipedia.org/wiki/Electrical_network).
You will need the electrical skills for
- understanding the behaviour of the total system
- for measuring of the finished PCB to perform a functional test

## ns_mech <br /> Practical Work with electrical components

The handling of electrical components differs from other handcraft activities in the electric current that comes into play and this can be dangerous if it is handled incorrectly.
The electric boards which are reproduced with the provided step-by-step guide have a low current flow as long as no solar panels are connected. Anyway, we want to point out the 5 safety rules of electrical engineering.
### 5 safety rules:
- switch off
- lock against reclosure
- check that lines and equipment are dead
- ground and short circuit phases
- cover, partition or screen of adjacent line sections

One of the most common mistakes when working with electrical components is causing a short circuit.
A short circuit means the direct contact of a plus and minus pole without any resistance in between. In the event of a short circuit the maximum current flows and without any fuse the used components will break. Therefore always make sure not to cause direct contact between a plus and a minus pole especially with working with batteries!.

For the board production you need the following previous knowledge in practical work.
- Hand soldering of boards with a soldering iron and solder
- a steady hand for placing the SMD components on the board
- Good eyes for recognizing the characteristics of each component

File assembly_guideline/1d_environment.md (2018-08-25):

---
title: "Environment and Tools"
excerpt: ""
permalink: /education/reproduction_environment/
---

- Prepare tools and place
-> foto of each part
  - table
  - crimping tool
  - screwdriver
  - side cutter
  - allen wrench
- Prepare material and components
  - Frame and Housing (in this case UniProKit)
    - screws, nuts
    - T-slot alu profile
    - 3D printed corner elements / connectors
    - bottom plate
    - housing plates
  - Battery pack
    - 3D printed battery case (bottom and cap -> download link to file)
    - battery cells
    - cell connectors
  - electrical components
    - Libre Solar components -> MPPT, *BMS*, (optional: CAN2Wifi)
    - (optional: RaspberryPi0)
    - wires - power wires (6 sq mm), balancing wires (2 sq mm)
    - ferrules, cable lugs
    - (optional: communication wire - ethernet cable)
   - plugs
     - *dc-output plugs (car plug, 2x)*
     - solar input plugs (Weidmüller PV Stick allows assembly w/o crimping and is compatible to MC4. Clips should be removed that the plug can be unmounted without tools)
     - *usb plugs*
     - *ON/OFF switch, pushbutton, integrated LED*
     - (optional: RJ45 jacks (2x))
     - (optional: epaper display+conncetion wire)

------------------------------------------------------

The Libre Solar project files are all open source and [stored on GitHub](https://github.com/LibreSolar). There is a separate repository for each PCB and an additional repository for the software.

Some of the repositories contain git submodules, so please use
```
git clone --recursive <repository>
```
instead of the download button on github.

## Hardware design

Except for some old boards, all Libre Solar electronics hardware is built using the open source PCB design software [KiCad 5](http://kicad-pcb.org/).

As KiCad version 5 contains lots of interesting new features (better rendering, rounded pads, STEP export, better symbol file format), the Libre Solar PCBs were recently converted to this version. Unfortunately, the files are not compatible with the older KiCad version 4 anymore. Please download the nightly builds or the stable KiCad version 5 as soon as it is released.

Custom footprints and symbols are saved in separate repositories:

- [https://github.com/LibreSolar/KiCad-footprints](https://github.com/LibreSolar/KiCad-footprints)
- [https://github.com/LibreSolar/KiCad-symbols](https://github.com/LibreSolar/KiCad-symbols)

The footprint library is directly included via the github import feature in KiCad. This feature does not exist for the schematics editor, so the schematic symbols are included via a git submodule.

## Software development

The firmware for the Libre Solar hardware is developed using the [ARM mbed OS](https://developer.mbed.org/) embedded software framework. This makes it possible to use easy-to-understand C++ syntax (similar to Arduino) and enhances community based software development.

We recommend to use Visual Studio Code and [PlatformIO](http://platformio.org/) as an IDE for software development.

All Libre Solar software repositories are structured as PlatformIO projects:

```
|--lib/
|  |--Foo
|  |  |- Foo.cpp
|  |  |- Foo.h
|  |--Bar
|  |  |- Bar.cpp
|  |  |- Bar.h
|--src/
|  |- config.h
|  |- main.cpp
|- platformio.ini
|- README.md
|- LICENSE
```

The main firmware is located in the `src` folder, external libraries or reuseable code are stored under `lib`.

The platformio.ini file contains some important settings which might have to be adjusted:

```ini
[env:nucleo]
platform = ststm32
framework = mbed
board = nucleo_f072rb
upload_protocol = stlink

# Settings:
# - enable float formatting for printf, adding approx. 7 kB of bin file size
# - C++11 to be able to define default values for struct members
# - Use low speed internal clock (LSI) for RTC (no LSE crystal on PCB)
build_flags =
    -Wl,-u_printf_float
    -std=c++11
    -DMBED_CONF_TARGET_LSE_AVAILABLE=0

# Custom Serial Monitor port
# monitor_port = /dev/ttyUSB1

# Custom Serial Monitor baud rate
monitor_baud = 115200
```

Of course, you can also use your favourite IDE and the mbed command line interface.

The chapter **Flashing** describes in detail how you connect the hardwar in order to upload the software to the device.

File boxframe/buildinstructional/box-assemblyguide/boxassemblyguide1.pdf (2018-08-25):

# Universal Prototyping Kit

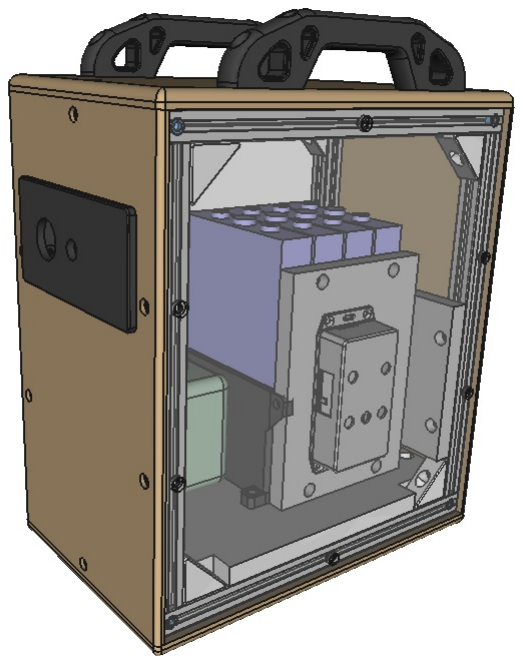
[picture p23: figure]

## UniProKit Box-Set UPKlib V. 2.02 Boxframe V.2 mobile Assembly Guide by OpenEcoLab Rahden, 08/2018

But in practice you may find it a bit tricky, to preplace the needed nutplates into the right slot for later use, eg. if you have finished the naked frame and then want to add the coverplates or other interieur
which assumes that there is already

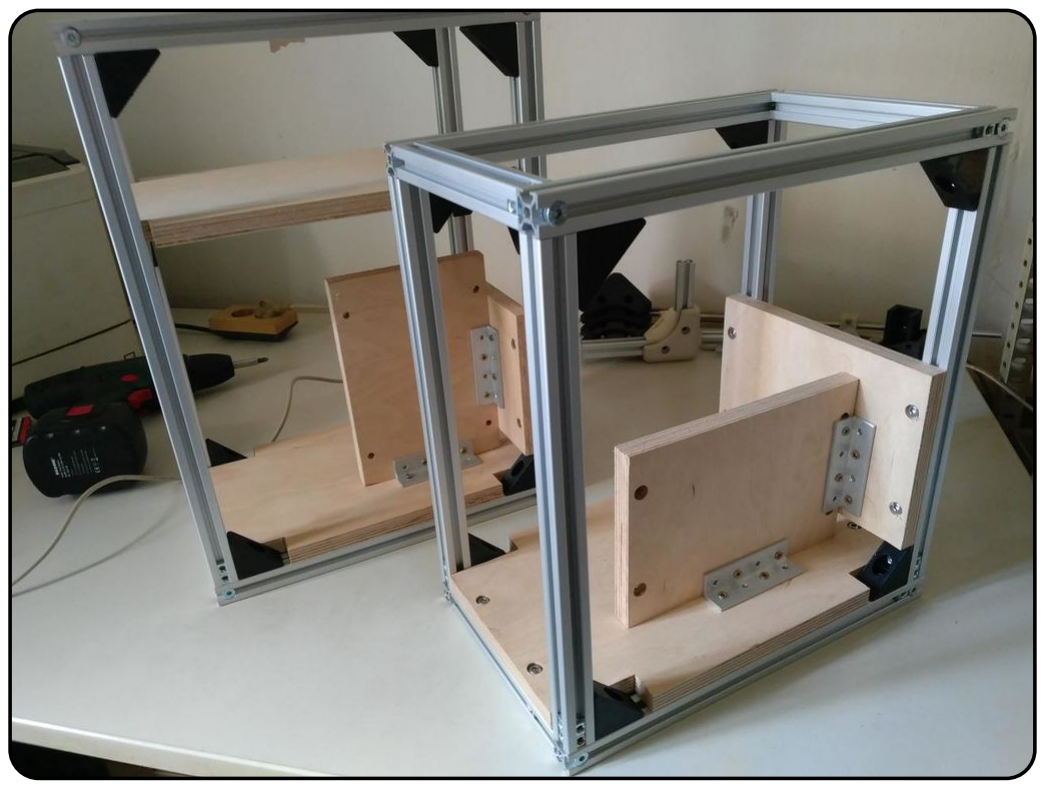
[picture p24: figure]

an appropriate nutplate in place, or better said in one certain slot of the extrusionprofile.

Depending on the stage of the assembly process it can either be still possible to move a nutplate into a slot, or not, Especially as more as you build up the frame some slots may be blocked eg. by the cornerscrews or by other beams. In this case there should already be one or more nutplates enclosed into the slot.

So its the best, to follow a certain choreography, movin some nuts into slots, then assemble a beam which encloses them.

Then again move some nuts into just these slots, which will be enclosed in the next assemblystep.

The guide aims to keep you an overview, which nuts to insert into which slot at a given step and then shows the next assembly step, to help you avoid forgetting some nutplates and having to disassemble later certain corners for moving the forgoten nutplates into it.

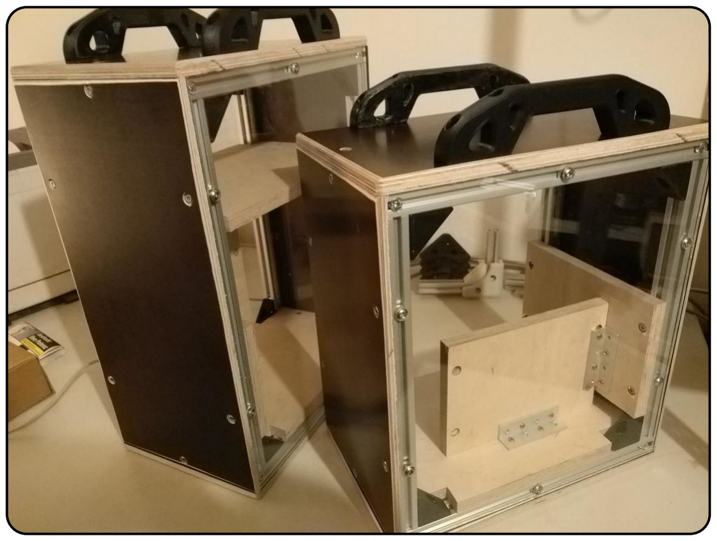
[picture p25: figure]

It's a bit like solving a rubikscube, as long as every step is applied at the right time and the right order, solving the puzzle is quick and easy.

Furthermore we start with building the upper frame, the lower frame and the upright pillars as sub-
assemblygroups, | before
connecting all totgether to a threedimensional framestructure.

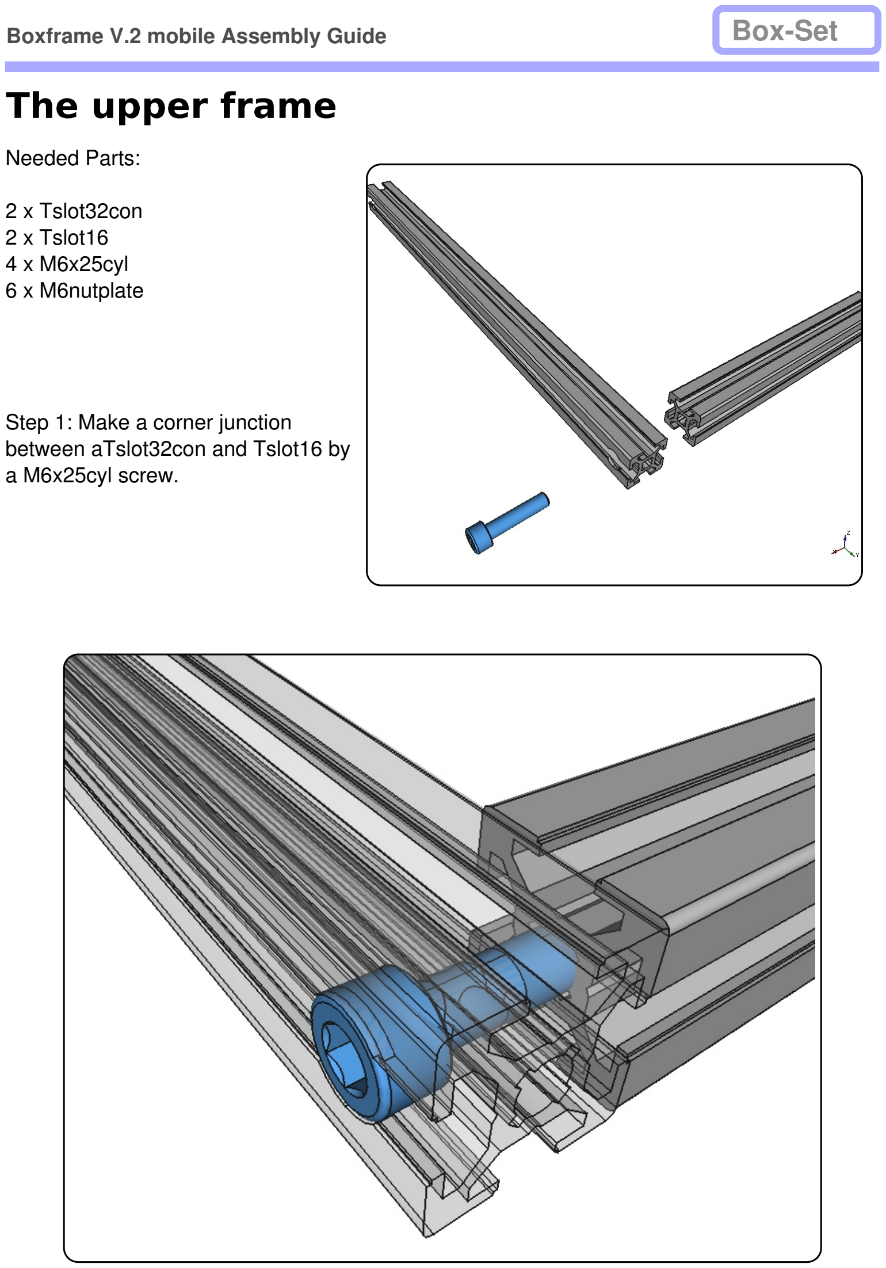
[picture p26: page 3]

Boxframe V.2 mobile Assembly Guide | Box-Set

Needed Parts:

2 x Tslot32con
2 x Tslot16
4 x M6x25cyl
6 x M6nutplate
Step 1: Make a corner junction between aTslot32con and Tslot16 by a M6x25cyl screw.

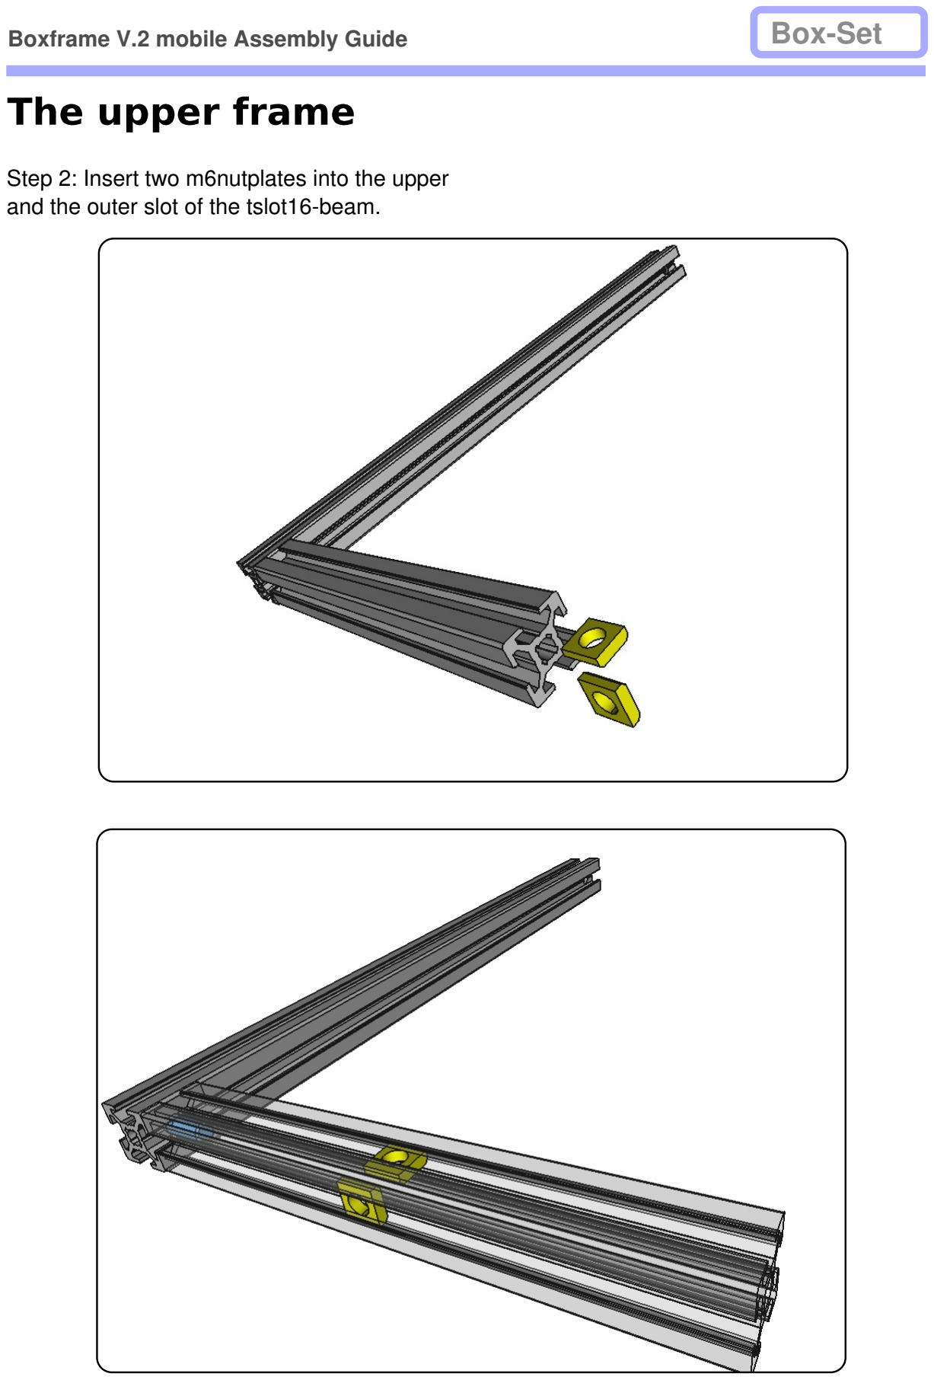
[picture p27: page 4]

Boxframe V.2 mobile Assembly Guide | Box-Set
Step 2: Insert two m6nutplates into the upper and the outer slot of the tslot16-beam.

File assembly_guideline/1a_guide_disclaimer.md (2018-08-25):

---
title: "DISCLAIMER"
permalink: /education/disclaimer/
---

Please notice our following disclaimer. Due to the fact we are not providing a product in the legal sense, we are also not providing any warranty in any aspect.

----------------------
The construction manual described here has been developed and tested by the team of cos(h) with care and to the best of our knowledge.

The team assumes no liability for the accuracy, completeness or quality of the information provided for the construction of the hardware described. Liability claims against the team for material, physical or immaterial damages caused by the use or non-use of the information provided or by the use of incorrect and/or incomplete information are excluded.

All information and instructions are non-binding. The team expressly reserves the right to change, supplement or delete parts of the pages or the entire offer without prior notice or to cease publication temporarily or permanently. By using the construction manual, the user accepts this disclaimer.

------------------------

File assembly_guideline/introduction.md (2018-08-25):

# Introduction

- Systembeschreibung
- welche komponenten
- ausgangslage
- ziel der schrittanleitung
- roadmap
-

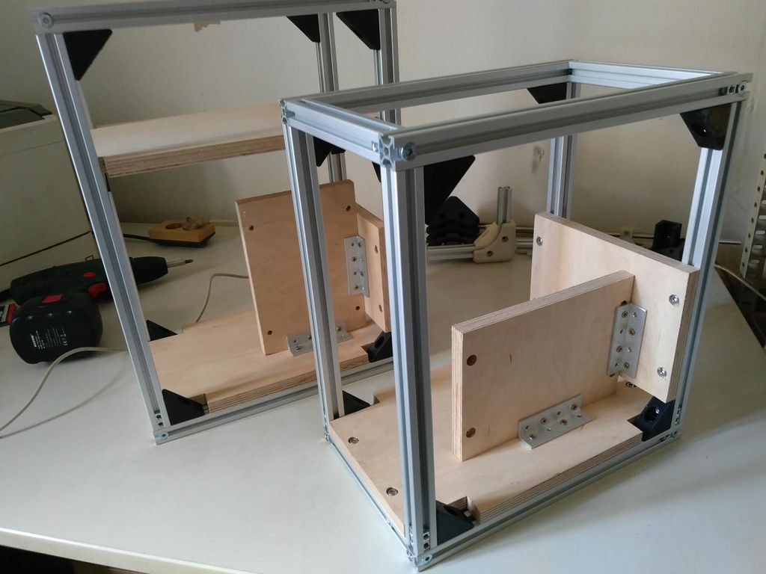
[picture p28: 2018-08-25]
boxframe/buildinstructional/box-assemblyguide/images/1024px-Photo_2018-04-28_18-47-50.jpg

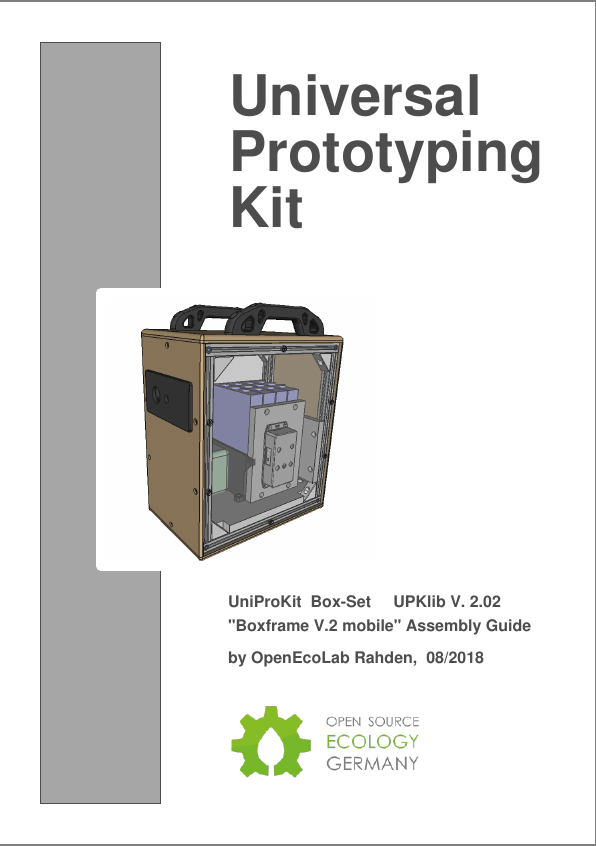
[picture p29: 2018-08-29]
boxframe/buildinstructional/box-assemblyguide/images/titlepage.png

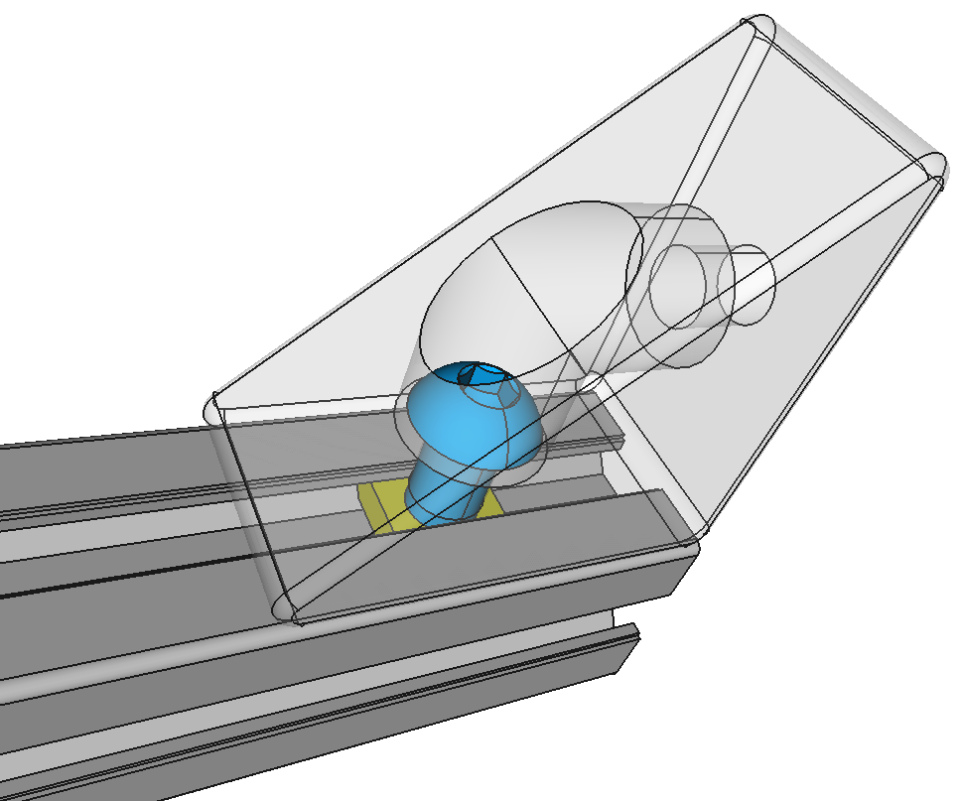
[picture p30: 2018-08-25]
boxframe/buildinstructional/upright/corner2.png

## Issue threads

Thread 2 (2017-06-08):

3D Box Design - first draft

mikelovic, 2017-06-08:
@DhavalGambhava  can you add a first draft of the box dimensions so we can check if the battery cells @case06 already designed  (#1) fit into it. Thank you!

DhavalGambhava, 2017-06-08:
@mikelovic
I uploaded 3D CAD Model and i added battery cells as well. It's fit well. Please check it.
Thxs!

DhavalGambhava, 2017-09-21:
@case06  Oliver, please upload your battery Box layout.

DhavalGambhava, 2017-09-23:
Guys !
I uploaded new final version of solar box. Please look it, and free fill to suggestion and verification.
Thxs.

Closed 2017-11-28.

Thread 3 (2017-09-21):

Safety concept

mikelovic, 2017-09-21:
putting fuse

case06, 2017-09-25:
https://www.youmagine.com/designs/stackable-fuseholder

https://www.thingiverse.com/thing:1057190

mikelovic, 2017-12-14:
integrated one main fuse. main security of system on BMS (battery protection, ...).

Closed 2017-12-14.

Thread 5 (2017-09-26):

integration of solarpanel holder

mikelovic, 2017-09-26:
@case06 @DhavalGambhava
just a thinking...
extend the batteriebox frame with a holder system for solarpanels. also based on UniProKit.

case06, 2017-09-26:
Do you mean something for clipping panels on the rooftop or something like a standalone-holder ? The latter could be interesting by combining it with a tracking system that moves the panel around, following the sun path. This could give you about 30% more energy harvested plus maybe 10% from the MPPT.

But there is one drawback: on windy/stormy days there are enormous forces directed towards the holder mounting because the panels have a lot of surface area where the wind can hook on.
Difficult to calculate the needed static (beyond my scope, this is engineers-stuff ;))

DhavalGambhava, 2017-09-28:
@mikelovic  I updated older design that can hold solar panel. Have you finalize solar module? If yes please send me name and specifications.

mikelovic, 2017-09-29:
@DhavalGambhava  yeah looks good. would be the easiest way to fix the panel near the box.
@case06 for a tracking system we would need some more parts (stepper, µC, ...). but yeah would be nice for sure. i think at the first step it would just be nice to have the opportunity to fix a panel.

case06, 2017-09-30:
btw. what type of inverter have you forseen ?

My recommendation for an entry-model is a Victron Phoenix 350/12V with 300W constant power (or the 800/12V version) and true sinus. I have already tested it in a productive environment and other projects like sunzilla uses it also, cause its known for its good quality.

link to datasheet: https://www.victronenergy.com/upload/documents/Datasheet-Phoenix-Inverter-180VA-1200VA-EN.pdf

link to dimensions (for freecad-modeling): https://www.victronenergy.com/upload/documents/Dimensions-Phoenix-Inverter-350.pdf

and/or

https://www.victronenergy.com/upload/documents/Dimensions-Phoenix-Inverter-800-1200.pdf

case06, 2017-09-30:
i have uploaded some pictures that show, how the junction of Dhajvals panelholder can be done in UniProKit.

https://github.com/CollectiveOpenSourceHardware/LibreSolarBox/tree/master/boxframe/panelsupport

and i am working on a upklib-based boxframe , have also uploaded some pics and freecad-files , see

https://github.com/CollectiveOpenSourceHardware/LibreSolarBox/tree/master/boxframe/upkframe

case06, 2017-09-30:
@DhavalGambhava   I have some 100W panels here, which have the outer dimensions 106 x 67 x 3.6 cm

DhavalGambhava, 2017-10-05:
@case06  I designed solar panel holder for 160 x 100 x 4 cm solar panel, and it can be also fit for smaller panel as well.

DhavalGambhava, 2017-12-16:
@mikelovic
@case06
We have flexible solar panel, so Holder can't hold perfectly to solar panel. Better to not use solar panel holder.

case06, 2017-12-16:
since the holder is sort of "telescopic" it could be used to give the flexible panel some tension. ;)

mikelovic, 2017-12-19:
i want to keep the solar panel holder as an optional module if someone wants to use not flexible solar panels.

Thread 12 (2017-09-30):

integration of inverter (optional)

mikelovic, 2017-09-30:
@case06 wrote:
btw. what type of inverter have you forseen ?

My recommendation for an entry-model is a Victron Phoenix 350/12V with 300W constant power (or the 800/12V version) and true sinus. I have already tested it in a productive environment and other projects like sunzilla uses it also, cause its known for its good quality.

link to datasheet: https://www.victronenergy.com/upload/documents/Datasheet-Phoenix-Inverter-180VA-1200VA-EN.pdf

link to dimensions (for freecad-modeling): https://www.victronenergy.com/upload/documents/Dimensions-Phoenix-Inverter-350.pdf

and/or

https://www.victronenergy.com/upload/documents/Dimensions-Phoenix-Inverter-800-1200.pdf

mikelovic, 2017-09-30:
i found on conrad this one.
https://www.conrad.de/de/netzwechselrichter-victron-energy-phoenix-12250-250-w-12-vdc-92-bis-17-v-schraubklemmen-schutzkontakt-steckdose-kab-1556057.html

250W output power is enough.
@martinjaeger @case06 would this one be good?

case06, 2017-09-30:
yes this would be also ok, but the 350/12V can be cheaper than this ;)

eg. here: https://www.photovoltaik4all.de/victron-phoenix-12/350-12v-dc-/-350va-ac

or here:

https://www.amazon.de/Phoenix-Wechselrichter-Schuko-Steckdose-Spannungswandler/dp/B01DT2I1S8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

For 20% lower price you get 50% more output  ;)

Closed 2017-11-28.

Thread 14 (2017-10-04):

Visualization

mikelovic, 2017-10-04:
visualization based on @openenergymonitor .
media: smart phone, tablet
communication: mppt -> esp; esp -> wlan-router

ThulasiKrishna, 2017-10-20:
Using Standalone Raspberry Pi for Monitoring.
 Process flow :
Solar Box --> Raspberry pi (Via Serial connector) ----> Push data to Energymonitor locally.

mikelovic, 2017-12-14:
new concept:
- extra PCB as CAN/Raspberry interface -> see: https://github.com/LibreSolar/CAN_RPi-ZeroW
- data send via CAN. stored on RasbperryPiZero as server
- access on Rasbperry via Wifi
- OEM server installed on Rasberry

mikelovic, 2019-03-20:
standard connnection to oem, solar-pv template, https://guide.openenergymonitor.org/applications/solar-pv/

- [ ] preparing parameter string
- [ ] function modul for easy setup options

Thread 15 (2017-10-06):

box elements - Brainstorming

mikelovic, 2017-10-06:
@DhavalGambhava  please take the layout from /batterycase from @case06 and extend it with

- components: MPPT, BMS, inverter, batteries
- plugs:
 - SolarInput
 - DC-Output (Fuse integrated),
 - (AC-Output->integrated in inverter)
 - USB-Plug+BuckConverter -> Dimension:48*23*14mm(L*W*H)
- display (MPPT+BMS) - Dimension:...
- Switch for DC Output
- Fuse:

case06, 2017-10-06:
the layout isnt in /batterycase, but in /boxframe/upkframe ;)

@DhavalGambhava : and btw. the boxframe-freecad files are made with freecad version 0.17, i have it not tested against the 0.16 version. If you have any diffiiculties contact me, or we can meet anyway again online and check things together. Maybe we can try this time the platform Jitsi (https://meet.jit.si/) to ensure that screen-sharing works in both directions ;)

DhavalGambhava, 2017-10-16:
@case06 : Can you please upload UPKframe 8 file again, because when i open this file then some parts are missing!!
Thxs..

case06, 2017-10-17:
@DhavalGambhava , @mikelovic

Make sure you use the Freecad version 0.17, then the missing parts should be there .

Concerning the dimensions: Normally it should fit, i think you have modelled the wrong inverter type, cause it has a height of 104 mm, which is typical for the Victron Phoenix 12/800 and the 12/1200 model.

What we use here is probably the 12/350 which has 72mm or the 12/250 which has 84mm height.  I dont know which one Michel has ordered, but in any case we will gain at least 20mm or even 30mmm headspace.  Additionaly we can sink down the top-plate, there is still enough empty space underneath.

I assume it will fit then.  If not, no problem, because i will bring the whole UniProKit with me on Friday, so we can use bigger length for the upward posts .  But i think this will be probably not ecessary.

case06, 2017-10-18:
I have just added the freecad file for the original hammond case which is around the bms and around the mppt .

https://github.com/CollectiveOpenSourceHardware/LibreSolarBox/blob/master/boxframe/upkframe/hammondcase.fcstd

mikelovic, 2017-11-30:
# ## current state:  @CollectiveOpenSourceHardware/00_reproduction_prototyping
## modules:
- **electric**: LibreSolar (MPPT+BMS), Inverter (Victron), ESP/Rasbperry
- **Batteries**: LiFePO4 (Calb), 72Ah, 3,2V, 230,5Wh - 4x -> 12,8V, 920Wh
- **Housing/Frame**: UniProKit, with corner elements for blending; wood plates for mounting electric parts and batteries
- **Interface**: Solarinput (MC4), DC-output (car plug), AC-output (schuko, integrated in inverter), main switch

mikelovic, 2017-12-02:
#meeting 2.12.17, fablab st. pauli:
##thinkings:
###interface:
- **solarinput**: problem: plug in/out nicht optimal; welche stecker eignen sich am besten.
-> verschiedene anschlussmöglichkeiten anbieten (vor-/nachteile); optionen: @martinjaeger
- **USB-Input**: Buck Converter+USB plug, @kruemel
- **USB-C**: possibilities to integrate in box, @jocogergely
- **RJ45-Jack**: connect more boxes together via CAN protocoll
- **Display**: basic information: SOC, P_in, P_out;
 - LEDs,
 - dotmatrix dispay, interface?
 - epaper, interface: SPI, connected to BMS, button to update date (standby Logo)

###electric:
- **inverter:** put outside the box (optional); optimize box layout w/o inverter; if someone needs inverter than connect outside the box

case06, 2017-12-02:
# **Box/housing:**

- ## **UPK**:   add mounting plates for connectors  (already in work).  The outer frame blends can contain cutout-sections, but should not be used for direct mounting of the connectors, mainly for two reasons:

1.  for statical reasons, the give not so much stability as a frame-integrated mounting-plate

2. Handling, maintainance, ergonomic: It should be possible to quickly screw of the blend at one side and then having access to the box-interieur. You don't want to have the blend-plate then still connected by serveral cables with the box.

mikelovic, 2017-12-14:
- [ ]  Battery case @jocogergely
- [ ]  PCB housing ideas @jocogergely
- [ ] Solar Plugs
- [ ] USB Buck converter @kruemel
- [ ] bill of materials

mikelovic, 2017-12-14:
## Bill of material V0.2:
-----------------
###box frame:
- UPK frame:
 - aluminium slot: size defined in 3D model
 - triangle connectors (for stabilization, @case06 whats the right word for it? :))
 - screws, ..., @case06  can you extend the list w/ all needed parts for the Uni Pro Kit w/o corner elements
- wood plates for cover -> thickness like alu profile
- wood plates for internal mounting of parts -> bottum, PCB mounting
- corner elements -> 3D modelled optinons (@jocogergely if you can you can make few suggestions, no prio)
- elect
###electric:
- MPPT, BMS, Gateyway/Server
- buck converter
###interface:
- dc-output plugs (car plug, 2x)
- solar input plugs
- usb plugs
- ON/OFF switch, pushbutton, integrated LED
- RJ45 jacks (2x)
- epaper display+conncetion wire
###connections:
- power wire (6mm^2, red+blue, each 1m)
- balancing wire (2mm^2, 1m)
- communication wire (ethernet cable, 0,5m)
- ferrules, cable lug

Closed 2019-03-20.

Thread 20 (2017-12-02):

Connectors mounting plate

case06, 2017-12-02:
I need the cutout-section dimensions of the connectors for making an appropriate mountingplate .

Closed 2017-12-14.

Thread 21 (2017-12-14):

Bill of Materials - V0.2

mikelovic, 2017-12-14:
material list for the second box v0.2.
information extended w/ supplier

mikelovic, 2017-12-14:
## Bill of material V0.2:
-----------------
### box frame:
- UPK frame:
  - aluminium slot: size defined in 3D model
  - triangle connectors (for stabilization, @case06 whats the right word for it? :))
  - screws, ..., @case06  can you extend the list w/ all needed parts for the Uni Pro Kit w/o corner elements
- wood plates for cover -> thickness like alu profile
- wood plates for internal mounting of parts -> bottom, PCB mounting, analog V0.1
- corner elements -> 3D modelled options (@jocogergely if you can you can make few suggestions, no prio)
### electric:
- MPPT, BMS, Gateyway/Server
- buck converter
### interface:
- dc-output plugs (car plug, 2x)
- solar input plugs
- usb plugs
- ON/OFF switch, pushbutton, integrated LED
- RJ45 jacks (2x)
- epaper display+conncetion wire
### connections:
- power wire (6mm^2, red+blue, each 1m)
- balancing wire (2mm^2, 1m)
- communication wire (ethernet cable, 0,5m)
- ferrules, cable lug

case06, 2017-12-15:
i checked thingiverse for handles, found the following looking promising:

https://www.thingiverse.com/thing:1228617
https://www.thingiverse.com/thing:130737
https://www.thingiverse.com/thing:12695
https://www.thingiverse.com/thing:2116139
https://www.thingiverse.com/thing:80040

the last one is my favourite.

mikelovic, 2018-01-10:
- [ ] offer from @case06 , UPK, specs from [V6 FreeCAD Design](https://github.com/CollectiveOpenSourceHardware/LibreSolarBox/tree/master/Solar%20Box_FreeCAD%20Design/Solar%20Box%20v_6_boxframe), additionally the wood plates (out-& inside), handles, screws, etc.

- [ ] offer from @martinjaeger , BMS, MPPT, Gateway

- [ ] other electric parts

mikelovic, 2018-01-11:
@case06 :
adaption of box design concerning wood enclosure.
decision for probosal from oliver.
wood plates: bottum and top -> 12mm, side elements -> 5mm, for inner structure

martinjaeger, 2018-02-02:
BOM moved to https://github.com/CollectiveOpenSourceHardware/LibreSolarBox/blob/master/BOM.md

--> Issue closed.

Closed 2018-02-02.

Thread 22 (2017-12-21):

box design - brainstorming

mikelovic, 2017-12-21:
in this issue we want to discuss about possible design elements for the batteries and electric components. based on the V0.1 of the Libre Solar Box.

**requirements:**
- ecological materials, upcycling elements
- easy production
- moveable
- scalable

case06, 2017-12-22:
some thoughts:

**Ecological materials:**
We can replace the cover-plates with wood-plates . I would recommend multiplex/plywood of 12mm. Question is how to fix them onto the frame.

**upcycling**

Hmm, in a project like this a more crucial aspect is the overall availability of the components from regular sources and a BOM which list that sources clearly.  But you can maybe upcycle/use any appropriate plate-materials for the cover plates.

**easy production**

Biggest prob is the availability of pcbs in small numbers eg. <= 10 pieces.  Commercial production from watterott is an option starting with 50 pieces, but we need smaller quantities for prototypes and their testing.

Possible solutions:
1. Pick&Place-machine
2. produce smaller batches manually (maybe as "production-workshop"-event at fabulous St.Pauli)

Btw., one thing which is even more important than "easy productions"  is "easy maintainance".

**moveable**

I have added some nice handles to the upklib. See https://wiki.opensourceecology.de/images/8/80/Upk_handles.jpg  and https://wiki.opensourceecology.de/images/6/64/Upk_handle2.jpg

**scalable**

Since the Mosfets are rated at 80A it is theoretically possible to drive it with up to 4 MPPT20s, what means up to 1.6 KWp PV-panels.  In practice we maybe better go with 3  MPPT20s and 60A to stay comfortable under the Mosfets limits equal to 1.2KWp PV.

This means to construct a backplane for the MPPTs, which consists of the CAN-bus data-lines (blue) and two 12V-Power-lines (black and red) like in this diagramm: https://wiki.opensourceecology.de/images/e/e8/Bms12v_systemuebersicht.png

mikelovic, 2018-02-01:
@case06
can you open the zip file [!here](https://github.com/CollectiveOpenSourceHardware/LibreSolarBox/tree/master/design_proposal) and import it in FreeCAD. Somehow i can't import it correctly in my FreeCAD version (0.16).
thank you in advance

mikelovic, 2018-02-01:
@FWdesign
Feedback:
- der gewichtsschwerpunkt sollte in der mitte liegen. die batterie sollten somit mittig in der box platziert sein.
- optional eine version ohne inverter (blaues modul). damit kann das ganze kleiner produziert werden. -> evtl zwei verschiedene version. oder modular erweiterbar um den inverter. anschluss an die box über DC anschluss.

case06, 2018-02-01:
When i imported the .igs file into freecad 0.17 it became extremely slow ... like swapping.
 Then i changed the view of the whole object into transparent and the performance was normal.

So i saved it into a freecad file

[https://github.com/CollectiveOpenSourceHardware/LibreSolarBox/blob/master/design_proposal/Solarbox_Trommel_transparent.fcstd](url)

with transparent view.

see
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

mikelovic, 2018-02-02:
@FWdesign
Feedback:
- der gewichtsschwerpunkt sollte in der mitte liegen. die batterie sollten somit mittig in der box platziert sein.
- optional eine version ohne inverter (blaues modul). damit kann das ganze kleiner produziert werden. -> evtl zwei verschiedene version. oder modular erweiterbar um den inverter. anschluss an die box über DC anschluss.

mikelovic, 2018-02-07:
@FWdesign
weight of batteries. 1.9 kg per cell. So for the 4 cells it is round about 8kg ( exactly 7,6kg).
here you find the specs http://evwest.com/support/CAM72FI%20Final.pdf

mikelovic, 2018-02-08:
@case06 @jocogergely @DhavalGambhava
hello CAD designer :) we need a new battery holder for this box design. the batteries lie horizontal. so we need again a mounting option and the space holder.
no prio. thank you

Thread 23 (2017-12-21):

repository structure

mikelovic, 2017-12-21:
@case06 @DhavalGambhava
for a clean repo structure I want to propose following structure:
.../LibreSolarBox/...
- ...components -> the needed components like UPK, libre solar CAD files, Batteryfiles, connectors, ...
 - .../components/frame
 - .../components/electric
 - .../components/battery
 - .../components/interface
- ...box_designs -> folder in which the different components are set together
 - .../box_designs/v01_upk -> current version
 - .../box_designs/v02_upk -> next version

--------------
so the main folder would be components and design.
in components we should list all possible components we can integrate in the box.
in designs we should list all possible design how the components can be connected and enclose.
--------------
feedback and suggestions are welcomed :) thx

case06, 2017-12-22:
i am fine with the folder-structure but be aware that a repo may have dependend local-repos (upstream, downstream) and you have to make sure, that everything changes accordingly if they try to synchronize.

So a suggestion:  Make a separate repo for the V2-Version and introduce there the suggested folder structure from the scratch. box-designs than can contain instead different sub-versions.

hoijui, 2019-03-30:
An ohter/additional suggestion: Make a script that creates the new folder structure and moves files around, fully automated. It can then be applied in forks, braches, and even to multiple/all commits in different git histories. It could be used to make a V2 repo, while keeping the (altored) project history.

This approach worked well for me in the past. one can continually apply the script to the old repo automatically, while still developing the script, until one is happy with the result, and while development is still going on in the project repo itsself.

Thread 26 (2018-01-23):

Battery Case

mikelovic, 2018-01-23:
For the V2 Box we want to adapt the battery mounting inside the box.

mikelovic, 2018-01-23:
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

First draft from @case06 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

mikelovic, 2018-02-01:
@case06 @jocogergely
concerning the mounting holes for the battery holder.
we should try to eleminate the wood plate around the batteries. so the vertical mounting hole should be adapted. i tought of mounting it on the aluminium rail (inside so there is space for the blend)

mikelovic, 2018-03-08:
@DhavalGambhava @jocogergely @case06 .
-> so we would need 2 different types of the case
 - for horizontal mounting
 - for vertical mounting

@DhavalGambhava you started with some designs at the last workshop, can you push the files please.

case06, 2018-03-09:
Not sure if i get you right.   To my understanding pure horizontal or pure vertical mounting isnt an option for reasons of stabilty and rigidity, so the case should be anyway mounted in more than one plane. At least on two planes.

Its no big problem to achieve that even when removing the wooden mountplate. I would suggest to indroduce two additional Tslot-Bars within the frame and thats it.  Then you can mount the cellpack anyway in vertical and if wanted as well in horizontal orientation.

DhavalGambhava, 2018-03-11:
@case06
Box Design till not finished, but I uploaded in GiutHub folder.
later I will Update this design model.

DhavalGambhava, 2018-06-02:
Hi all,
@mikelovic  @case06 @jocogergely

I just uploaded new design of Battery Case/ Holder. So we don't required wood to hold battery  :-)
@case06, Oliver  As we discuss last time during workshop, so please check the design that it can be printed in 3D printer or not ?

There is still open point regarding to the **Top cover** of Battery Case,
@jocogergely  , Jozsef   Is it possible for you to design this part ?

@mikelovic , Michel I design this case according to both design type of box 1) Uni-pro kit Battery box and 2) Round design (by Karlsruhe friends). So, check it out this design, if you have any comments please let me know ;-)

Thank you and have a nice weekend to all !

case06, 2018-06-04:
@DhavalGambhava   hey, cool stuff, looks great !  And yes, this should be printable, as far as i can see you have taken all critical aspects that we discussed into account.

Maybe there will be a minor imperfection in the holes of the junction-corners but thats probably neglectable (and i would do it the same way) so we can give it a try.

case06, 2018-06-04:
two suggestions for optimizations:

- shaping the junction holes hexagonal for snug-fit with hexagonal nut. I am not sure wether the (round) hole size will be big enough for the nut. But given that, one can make it hot with an soldering iron and melt it perfectly into the hole

- maybe it would be good for stability, to make the "windows" in the wall smaller (and therefore the corner-pillars wider). Reason is the grain-direction: the weak-point in 3d-prints is always the adhesion between layers. So if you have a long structure with a small base-area it can more easily break along the length. A bigger base-area means more layer-adhesion.

But it depends also from other aspects like material-quality and printing-parameters (e.g. temperature), how well the layer-adhesion is.  So we should give it a first try as it is, maybe its already sufficient.

DhavalGambhava, 2018-06-23:
@mikelovic  @case06
I added Cover in battery case, which protect the connection between batteries. Please look in "Battery Case_Holder_v_4" file.

case06, 2018-06-23:
Looks good, but you should maybe add in the top cover a few holes for the cables :)

DhavalGambhava, 2018-07-04:
@case06   Done!! Thxs for reminder, I added slot for wire in cover.

@mikelovic  @case06  I found it's bit complected to install/ make slot to hold MPPT & BMS on battery case, because battery case wall is like wire frame !! (to reduce material use) & reduired more complex design + to we have to prepare in 3D printer !
Please give some suggestion on it, else we can make bar slot and then glue it on Battery case! which is not good :-(

mikelovic, 2018-07-05:
@DhavalGambhava  looks very good! thank you!
Would it be one possibility to mount the electric cases like this?

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

case06, 2018-07-05:
A click-option would be very cool, but is maybe not so easy to construct (at least i never did so far). But when thinking about click-option, one could also think about making the two halfes of the Batterycase and its Top-lid as well clickable.  I would see that as a longterm goal/option.

The best way to achieve a good screw-mounting is in my opinion to make the related side wall compact and thicker, about 10 or 12 mm and integrate apprpriate holes, into which the nuts can be embedded.

IOW, we use the Nut as a thread which is implemented in the case and screws can be driven into, without the need to hold/block the nut with a pliers or something.

case06, 2018-07-05:
Another thing: I discussed several weeks ago with Martin, how a future version of the pcb-case should look like, and we came up with a version which is not any longer sandwiched/piggy-backed, but having the pcbs beside each other, for thermal reasons AND we would like to add a heatsink into the case.

This would imho lead to a conformation like this:  https://wiki.opensourceecology.de/images/4/4e/Photo_2018-07-05_14-17-40.jpg

 And btw. the ffc foil-cable and its connector should then be replaced with a regular one, because its more expensive, difficult to order and can break more easily, so there is no real reason or advantage in a  ffc-cable.

Closed 2018-08-25.

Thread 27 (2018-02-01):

Testing - Libre Solar Box

mikelovic, 2018-02-01:

mikelovic, 2018-02-01:
specification of used solar panels at the fablab.
see: https://www.jws-store.de/solarenergie/solarpanels-mono-12volt/55watt-solarpanel-12-volt-monokristallin/a-194/

## Technische Daten:
Nennleistung Pmax 140 Watt
Spannung bei Nennleistung Vpmax 22 Volt
Leerlauf Spannung Voc 26 Volt
Kurzschluss Strom Isc 6,87 Ampere
Strom bei Nennleistung Ipmax 6,36 Ampere
Temperaturbereich -40°C / + 85°C
Toleranz +/-3 %
Flexible monokristalline hochleistungs Solarzellen von SUNPOWER, Wirkungsgrad über 21%
Abmessungen: 1490 x 560 x 3mm
Gewicht 2 kg

mikelovic, 2018-04-05:
## Meeting 05.04

*#1* Testing of components (MPPT, BMS)
- what to test, how to test, when to test

*#2* Installation of Energy System in Fablab St.Pauli
- which loads, how much solar power, how much capacity -> design and layout

*#3* Monitoring
- energy data monitoring and analysis

mikelovic, 2018-04-12:
## Meeting 12.04

basic concept
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

concept for discussion @CollectiveOpenSourceHardware/00_reproduction_prototyping

SchneiderAn, 2018-04-19:
[Testing MPPT.pdf](https://github.com/CollectiveOpenSourceHardware/LibreSolarBox/files/1928263/Testing.MPPT.pdf)

SchneiderAn, 2018-04-19:
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

SchneiderAn, 2018-04-19:
Testing the BMS:
1.	find out the BMS requirements / What does the BMS needs to do:
•	Voltage balancing
•	Temperature checking
•	etc
2.	Testing if the BMS fulfils each requirement:
•	Measure the voltage at each cell
etc

mikelovic, 2018-05-17:
Messplan:

### MPPT
- min/max Strom: 0..20A
- min/max Spannung: 16V..55V
- Effizienzpunkte (eta(P))
- Spannungsqualität am Ausgang (Regelverhalten bei Sprung am Eingang)
- MPPT Qualität (Abweichung, Zeit)

### BMS
- min/max Strom: 0..30A
- (Schutzmechanismen - Ladeschlussspannung, Tiefentladeschutz)
- Effizienzpunkte (eta(P))

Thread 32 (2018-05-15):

electrical_layout

mikelovic, 2018-05-15:
started with the electrical layout of the box.
interface/plugs:
- power/on button, with integrated LED
- RJ45 plug
- USB Adapter
- DC-out, 12V car plug, 2x
- PV-in, MC4, 2x
electronics:
- libre solar - MPPT20A
- libre solar - BMS-5s
- libre solar - gateway (integr. raspberrypi0)
- (optional) inverter 12Vdc/230Vac
batteries:
- calb, LiFePO2, 4x

case06, 2018-06-04:
aehm ... the calb batteries are LiFePO4   ;)

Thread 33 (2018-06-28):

Assembly Day Pt.3 - Assembly and Documentation of the SolarBox Process

mikelovic, 2018-06-28:
# Assembly Workshop at the Fablab St.Pauli, 08. July 2018

### Preparation Steps
- Software tools
  - FreeCAD,
- Prepare of tools and place
  - table
  - crimping tool
  - screwdriver
  - side cutter
  - allen wrench
- Prepare material and components
  - Frame and Housing (in this case UniProKit)
    - screws, nuts
    - T-slot alu profile
    - 3D printed corner elements / connectors
    - bottom plate
    - housing plates
  - Battery pack
    - 3D printed battery case (bottom and cap -> download link to file)
    - batteries
    - battery connectors
  - electrical components
    - Libre Solar components -> MPPT, BMS, (optional: CAN2Wifi)
    - (optional: RaspberryPi0)
    - wires - power wires (6 sq mm), balancing wires (2 sq mm)
    - ferrules, cable lugs
    - (optional: communication wire - ethernet cable)
   - plugs
     - dc-output plugs (car plug, 2x)
     - solar input plugs (Weidmüller PV Stick allows assembly w/o crimping and is compatible to MC4. Clips should be removed that the plug can be unmounted without tools)
     - usb plugs
     - ON/OFF switch, pushbutton, integrated LED
     - (optional: RJ45 jacks (2x))
     - (optional: epaper display+conncetion wire)

### Assembly Steps
1. Frame assembly
 1.1 nuts into t-slot profile (
 1.2 place profile in rectangle, place corner elements between profiles, screw together
 1.3 repeat
-> result: 2 connected rectangle frame
 1.4 connect the 2 rectangle frames with profile
-> result: boxframe
2. screw bottom plate on bottom side of boxframe
-> boxframe with bottom plate
3. cut and crimping wires
 3.1 ...
4. battery pack assembly -> !!!!!safety note!!!!!
 4.1 put battery cells in battery case (bottom part)
 4.2 connect battery cells together
 4.3 connect balancing wires with cells
 4.4 connect power wires with battery cells
 4.5 screw battery pack with bottom plate
5. mouting of electric components
...

case06, 2018-07-08:
Making fotos for instructional of each phase when dissassembling:

If possible, it would be great if you could make also some fotos, which shows for each side the placement (and numbers) of the nuts (sitting in the slots).  This is the key-information needed when assembling a box the first time, in order to avoid repeatedly re-opening the frame for adding some forgotten nuts  .  Having that key would be a real  nice improvement of our doku 😃

Aehm ... macht einfach möglichst viele fotos beim  disasssemblen, ich such mri dann schon das passende raus.  Und welch besonders wichtig sind, das hatte ich schon gepostet:   Fotos, welche zeigen, wo und wieviel Nutenplatten im T-Slot stecken, wenn die Seitenplatten entfernt sind.  Und die von jeder Seite einzeln. Damit man die von vornherein korrekt abzählen kann und nicht immer wieder die Verbindungen neu aufmachen muss, weil man diese oder jene Nutenplatte vergessen hat.

Closed 2018-08-25.

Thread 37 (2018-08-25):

Assembly Guideline

mikelovic, 2018-08-25:
Production of OER - Solarbox Assembly

structure/navigation
- disclaimer
- introduction
- needed skills
- tools&materials
- boxframe assembly
- mounting (batterypack, electr. parts, plugs)
wiring (batterypack, components, plugs)

@case06
- boxframe assembly
Michel:
- mounting
@rkrenzler
- wiring

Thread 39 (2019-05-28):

BOM for lead acid version

martinjaeger, 2019-05-28:
If the box uses lead-acid batteries, the BMS is not needed, making the box layout more simple.

The following material would be needed:
- Box housing
- Libre Solar MPPT 10A (incl. USB output)
- DC 12V outlet plugs (at least 2), e.g. Reichelt BST 23 or BST 23 FEB
- 5V USB outlet plug, e.g. Reichelt BST 67322500
- PV module connectors for panel, e.g. Weidmüller PV stick
- On/off Switch to disconnect battery (at least 20A DC)
- 12V battery connectors, e.g. Reichelt BATTERIEKLEMMEN
- Fuse holder + fuse, e.g. Reichelt LITT 0FHA0002ZXJ
- Wires (4-6 mm²) and ferrules / crimp terminals

ToDo: Detailed build-up description.

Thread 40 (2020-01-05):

nach (kosten)freier cos(h) Anzeige in Engineering-Magazinen anfragen

eMPee584, 2020-01-05:
Haue das hier gerad mal hier als Platzhalter rein..
Eine schöne Einladung zum Open Engineering.. um mehr Ingenieure zu begeistern von der Methode u. den Tools..

mikelovic, 2020-01-14:
Hi Marcel,

Die mail kam in meinen Spam Ordner leider.

Um was gehts hier? Können wir das in Telegram bequatschen :)

Gruß Michel

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

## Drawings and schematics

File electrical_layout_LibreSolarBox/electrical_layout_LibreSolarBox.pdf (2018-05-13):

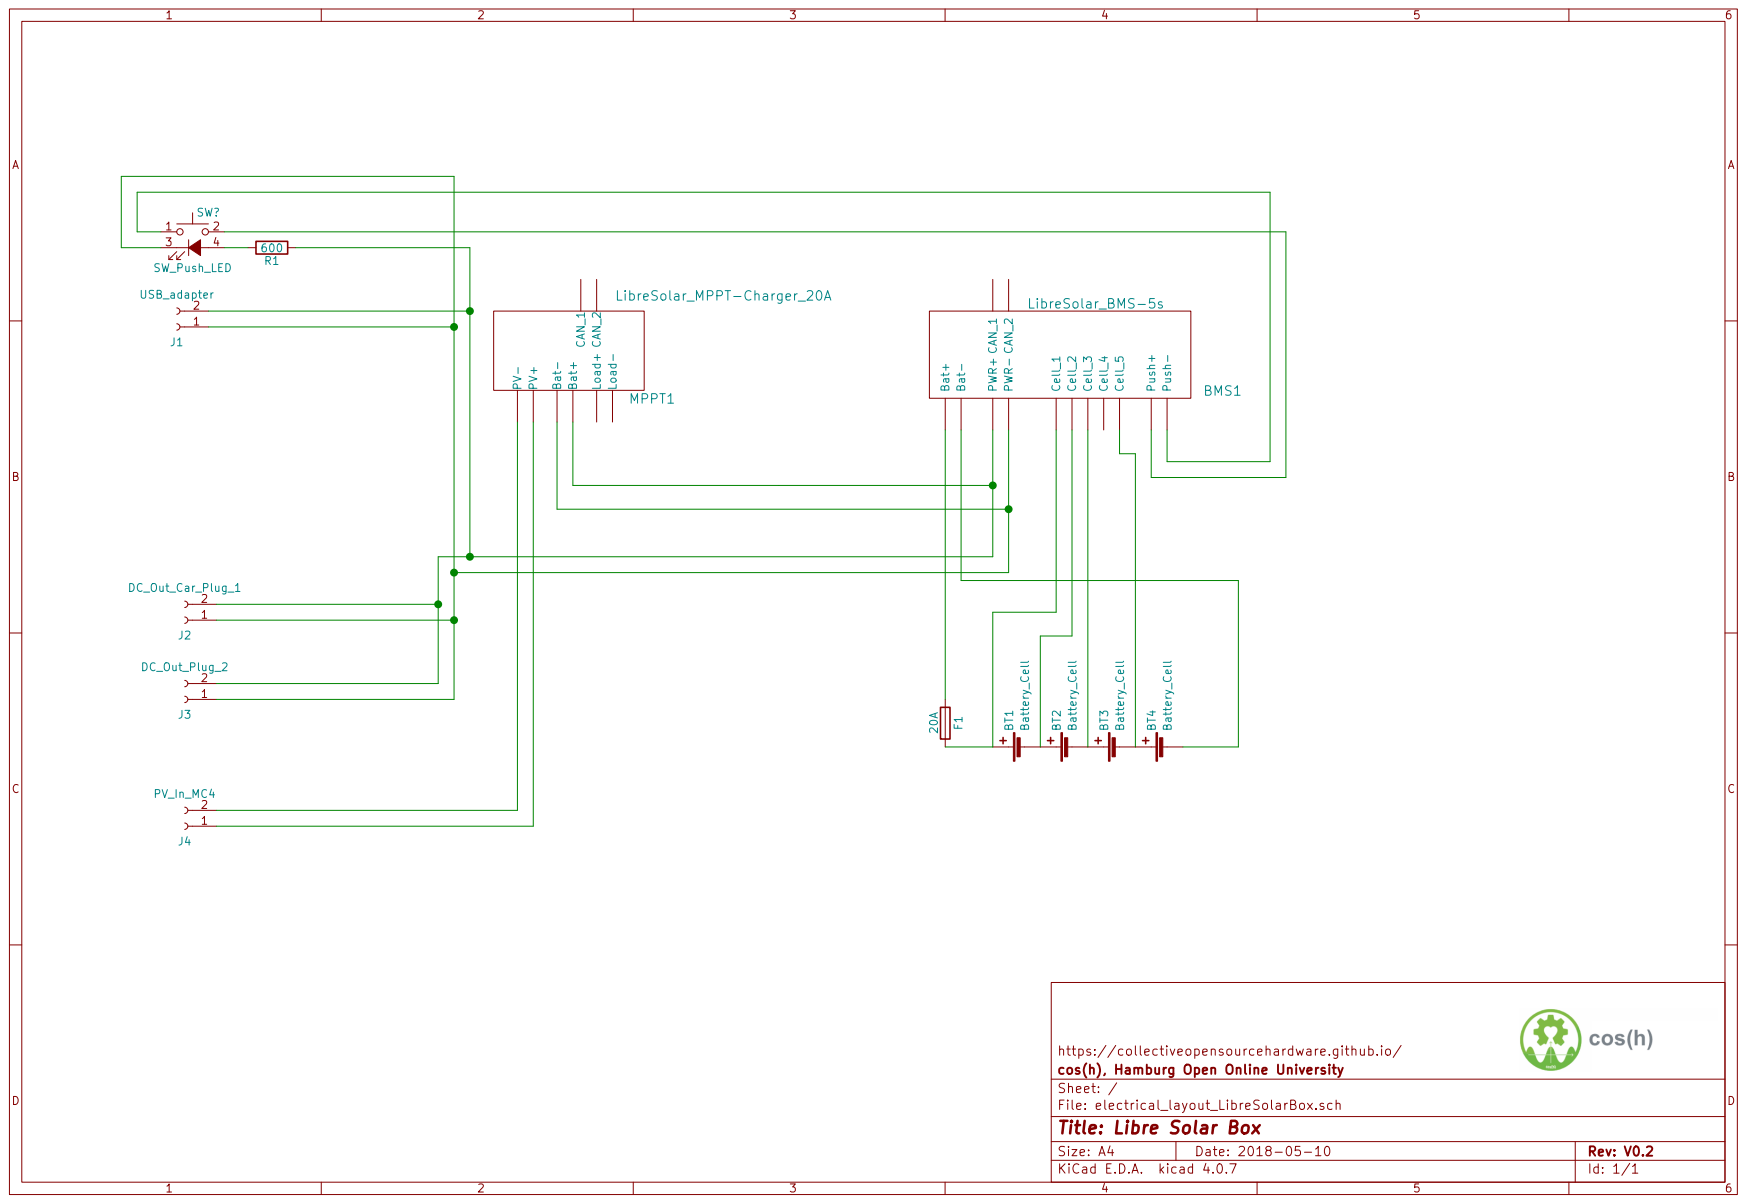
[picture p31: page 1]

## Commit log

2017-05-19 FreeCAD files for batterycase added
    [cam72_calb3.fcstd]
2017-09-24 added recent and reworked version of UniProKit Library upklib_v2 ; it contains a 3D-part-library in FreeCAD fileformat, with all stuff needed for constructing, prototyping and building a SolarBox fra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
    [ISO_7380_M8_x_10_10S.stp, all_angles.fcstd, all_flatplates.fcstd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]
2017-09-24 added some pictures of the solarbox frame and some others (offtopic) showing a draft of a stencil printer/frame which is also based on the upklib
2017-09-29 added junction for solarpanel-support
    [nutplatescrew.fcstd]
2017-09-30 added flat frame and boxframe with screws and nutplates
    [UPKframe2c.fcstd, UPKframe3.fcstd, cornerstonescrewnut.fcstd]
2017-09-30 added frame4 image
2017-09-30 added frame4 freecadfile
    [UPKframe4.fcstd]
2017-10-02 added angles and top plate
    [UPKframe5.fcstd, UPKframe6.fcstd, nutplate12screw.fcstd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]
2017-10-06 added Frontplate
    [UPKframe7.fcstd, UPKframe8.fcstd, bottom_plate.fcstd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]
2017-10-14 added slider to upklib
    [carriage_8mm_rods_v02.FCStd, idlerSide_8mm_rods_v02.FCStd, motorSide_8mm_rods_v02.FCStd]
2017-10-18 hammond case added
    [hammondcase.fcstd]
2018-01-10 added new design with external wooden plates
    [UPKframeNG1f.fcstd, boxhandle1j.fcstd, frontback.fcstd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]
2018-01-15 added lower frameversion as NG2
    [UPKframeNG2.fcstd, UPKframeNG2b.fcstd, UPKframeNG2c.fcstd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]
2018-01-25 added new design for gateway case
    the design need eventually some changes
    [gateway_case_botom_0.1.FCStd, gateway_case_top_0.1.FCStd]
2018-01-25 added new design for gateway case
2018-02-01 added frame for new Version v.02
    [UPKframeNG2e.fcstd, UPKframeNG2f.fcstd, UPKframeNG2g.fcstd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]
2018-05-13 add electrical layout
    added electrical layout and wiring of the box components
    [electrical_layout_LibreSolarBox.kicad_pcb, electrical_layout_LibreSolarBox.sch]
2018-07-10 convert to ods
    [Bill of Materials.ods]
2018-07-15 append assembly notes from 8 July 2018.
2018-08-25 remove not related instructions from "boxframe assembly" chapter
2018-08-25 added pics for assembly guide
    [cover1.fcstd, cover2.fcstd, cover3.fcstd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]
2018-08-25 added scribusfile for assembly guide
2018-08-29 added titlepage of assembly guide
2018-08-29 added pdf and scribus-sourcefiles of assembly guide
2018-08-29 added freecad sourcefiles for assembly guide
    [cover10.fcstd, cover11.fcstd, cover12.fcstd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]
